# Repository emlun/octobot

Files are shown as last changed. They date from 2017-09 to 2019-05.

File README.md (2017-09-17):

octobot
=======

This is a hobby project of building an ALU, CPU, computer, or whatever it ends
up as before I tire of it, from basic components. Think of it as a learning and
art project more than anything practically useful.

Inspirations include:

- [That ALU built in minecraft][minecraft]
- [Boldport Club][boldport-club] for sending me beautiful, fun, whimsical and/or
  useful kits to assemble; and for its community of other tinkerers showing off
  their projects
- [Crash Course Computer Science][cccs] for making me think "that should be fun,
  how hard could it be?"
- The [MOnSter 6502][monster] and [Megaprocessor][megaprocessor]

Special thanks also to the [Boldport Club][boldport-club] community for
providing newbie help as I try to figure these things out!

[cccs]: https://www.youtube.com/watch?v=1I5ZMmrOfnA&list=PL8dPuuaLjXtNlUrzyH5r6jN9ulIgZBpdo&index=6
[minecraft]: https://www.youtube.com/watch?v=LGkkyKZVzug
[boldport-club]: http://www.boldport.club/
[monster]: http://monster6502.com/
[megaprocessor]: https://www.youtube.com/watch?v=z71h9XZbAWY

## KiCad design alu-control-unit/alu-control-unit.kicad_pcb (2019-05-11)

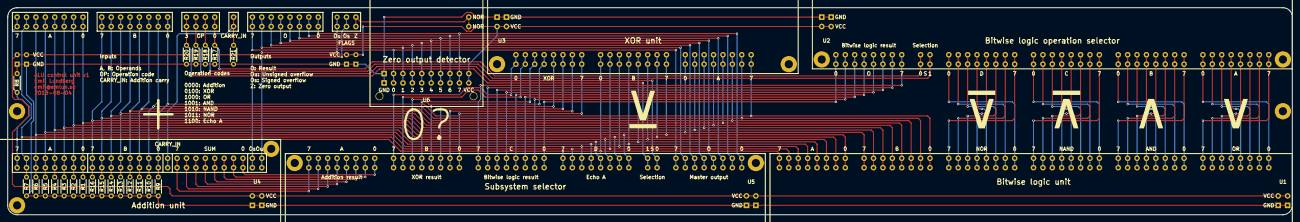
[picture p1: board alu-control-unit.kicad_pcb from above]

Board: 2 copper layers, 346.7 x 55.9 mm, 35 parts (0 on the bottom side), 90 nets.

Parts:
J1, J2, J5: Conn_01x08; J8x2-double_8_bit_bus_connector_1_indexed
J3: Conn_01x04; J4x2-double_4_bit_bus
J4: Conn_01x01; J1x2-double_1_bit_bus
J6: Conn_01x03; J3x2-double_3_bit_bus
J7, J7#2: PWR-2_pole_power_connector; PWR-double_2_pole_power_connector
R1, R2, R3, R4, R5, R6, R7, R8, R9, R10, R11, R12, R13, R14, R15, R16, R17, R18, R19, R20, R21: R; R_Axial_DIN0204_L3.6mm_D1.6mm_P5.08mm_Horizontal
U1: 8-bit-bitwise-logic
U2, U5: 4-way-8-bit-bus-selector
U3: 8_bit_xor; 8-bit-xor
U4: 8_bit_adder; 8-bit-adder
U6: 8-input-NOR; 8-input-nor

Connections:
/a0: J1.8, R1.2, U1.8, U3.9, U4.8, U5.32
/a1: J1.7, R2.2, U1.7, U3.10, U4.7, U5.31
/a2: J1.6, R3.2, U1.6, U3.11, U4.6, U5.30
/a3: J1.5, R4.2, U1.5, U3.12, U4.5, U5.29
/a4: J1.4, R5.2, U1.4, U3.13, U4.4, U5.28
/a5: J1.3, R6.2, U1.3, U3.14, U4.3, U5.27
/a6: J1.2, R7.2, U1.2, U3.15, U4.2, U5.26
/a7: J1.1, R8.2, U1.1, U3.16, U4.1, U5.25
/and0: U1.40, U2.16
/and1: U1.39, U2.15
/and2: U1.38, U2.14
/and3: U1.37, U2.13
/and4: U1.36, U2.12
/and5: U1.35, U2.11
/and6: U1.34, U2.10
/and7: U1.33, U2.9
/b0: J2.8, R9.2, U1.16, U3.1, U4.16
/b1: J2.7, R10.2, U1.15, U3.2, U4.15
/b2: J2.6, R11.2, U1.14, U3.3, U4.14
/b3: J2.5, R12.2, U1.13, U3.4, U4.13
/b4: J2.4, R13.2, U1.12, U3.5, U4.12
/b5: J2.3, R14.2, U1.11, U3.6, U4.11
/b6: J2.2, R15.2, U1.10, U3.7, U4.10
/b7: J2.1, R16.2, U1.9, U3.8, U4.9
/carry_in: J4.1, R21.2, U4.17
/ins0: J3.4, R17.2, U2.34
/ins1: J3.3, R18.2, U2.33
/ins2: J3.2, R19.2, U5.34
/ins3: J3.1, R20.2, U5.33
/logic_out0: U2.42, U5.24
/logic_out1: U2.41, U5.23
/logic_out2: U2.40, U5.22
/logic_out3: U2.39, U5.21
/logic_out4: U2.38, U5.20
/logic_out5: U2.37, U5.19
/logic_out6: U2.36, U5.18
/logic_out7: U2.35, U5.17
/nand0: U1.32, U2.24
/nand1: U1.31, U2.23
/nand2: U1.30, U2.22
/nand3: U1.29, U2.21
/nand4: U1.28, U2.20
/nand5: U1.27, U2.19
/nand6: U1.26, U2.18
/nand7: U1.25, U2.17
/nor0: U1.24, U2.32
/nor1: U1.23, U2.31
/nor2: U1.22, U2.30
/nor3: U1.21, U2.29
/nor4: U1.20, U2.28
/nor5: U1.19, U2.27
/nor6: U1.18, U2.26
/nor7: U1.17, U2.25
/ofl_sgn: J6.2, U4.26
/ofl_uns: J6.1, U4.27
/or0: U1.48, U2.8
/or1: U1.47, U2.7
/or2: U1.46, U2.6
/or3: U1.45, U2.5
/or4: U1.44, U2.4
/or5: U1.43, U2.3
/or6: U1.42, U2.2
/or7: U1.41, U2.1
/out0: J5.8, U5.42, U6.1
/out1: J5.7, U5.41, U6.2
/out2: J5.6, U5.40, U6.3
/out3: J5.5, U5.39, U6.4
/out4: J5.4, U5.38, U6.5
/out5: J5.3, U5.37, U6.6
/out6: J5.2, U5.36, U6.7
/out7: J5.1, U5.35, U6.8
/out_zero: J6.3, U6.9
/sum0: U4.25, U5.8
/sum1: U4.24, U5.7
/sum2: U4.23, U5.6
/sum3: U4.22, U5.5
/sum4: U4.21, U5.4
/sum5: U4.20, U5.3
/sum6: U4.19, U5.2
/sum7: U4.18, U5.1
/xor0: U3.17, U5.16
/xor1: U3.18, U5.15
/xor2: U3.19, U5.14
/xor3: U3.20, U5.13
/xor4: U3.21, U5.12
/xor5: U3.22, U5.11
/xor6: U3.23, U5.10
/xor7: U3.24, U5.9
GND: J7.1, J7#2.1, R1.1, R2.1, R3.1, R4.1, R5.1, R6.1, R7.1, R8.1, R9.1, R10.1, R11.1, R12.1, R13.1, R14.1, R15.1, R16.1, R17.1, R18.1, R19.1, R20.1, R21.1, U1.50, U2.44, U3.26, U4.29, U5.44, U6.11
VCC: J7.2, J7#2.2, U1.49, U2.43, U3.25, U4.28, U5.43, U6.10

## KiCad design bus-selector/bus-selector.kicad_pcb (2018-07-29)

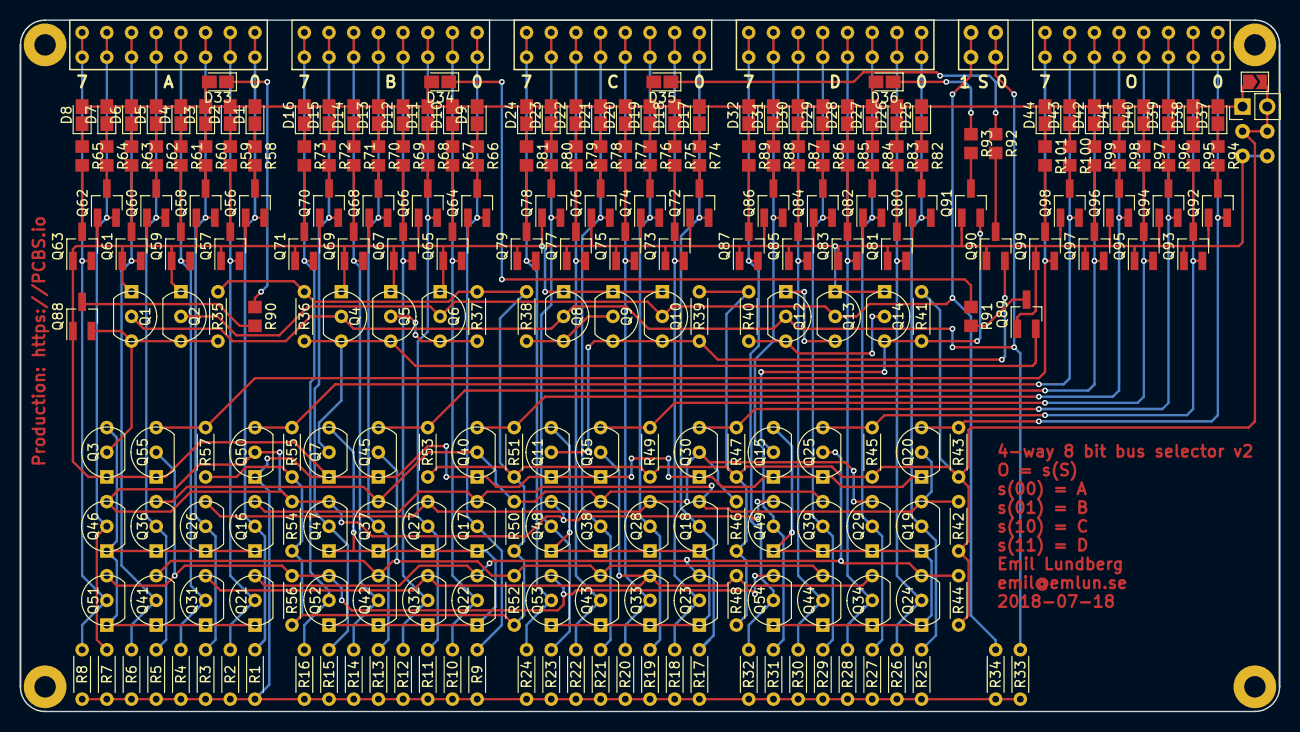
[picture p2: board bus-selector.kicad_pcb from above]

Board: 2 copper layers, 129.5 x 71.1 mm, 253 parts (0 on the bottom side), 153 nets.

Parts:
D1, D2, D3, D4, D5, D6, D7, D8, D9, D10, D11, D12, D13, D14, D15, D16, D17, D18, D19, D20, D21, D22, D23, D24, D25, D26, D27, D28, D29, D30, D31, D32, D33, D34, D35, D36, D37, D38, D39, D40, D41, D42, D43, D44: LED; LED_0805_2012Metric_Castellated
J1, J2, J3, J4, J6: Conn_01x08; J8x2-double_8_bit_bus_connector_1_indexed
J5: Conn_01x02; J2x2-double_2_bit_bus
J7: PWR-2_pole_power_connector; J2x2-double_2_pole_connector
JP1: Jumper_2_Open; PinHeader_1x02_P2.54mm_Vertical
JP2: SolderJumper_2_Open; SolderJumper-2_P1.3mm_Open_TrianglePad1.0x1.5mm
Q1, Q2, Q3, Q4, Q5, Q6, Q7, Q8, Q9, Q10, Q11, Q12, Q13, Q14, Q15, Q16, Q17, Q18, Q19, Q20, Q21, Q22, Q23, Q24, Q25, Q26, Q27, Q28, Q29, Q30, Q31, Q32, Q33, Q34, Q35, Q36, Q37, Q38, Q39, Q40, Q41, Q42, Q43, Q44, Q45, Q46, Q47, Q48, Q49, Q50, Q51, Q52, Q53, Q54, Q55: 2N7000; TO-92_Molded_Wide_Inline
Q56, Q57, Q58, Q59, Q60, Q61, Q62, Q63, Q64, Q65, Q66, Q67, Q68, Q69, Q70, Q71, Q72, Q73, Q74, Q75, Q76, Q77, Q78, Q79, Q80, Q81, Q82, Q83, Q84, Q85, Q86, Q87, Q88, Q89, Q90, Q91, Q92, Q93, Q94, Q95, Q96, Q97, Q98, Q99: 2N7000; SOT-23_Handsoldering
R1, R2, R3, R4, R5, R6, R7, R8, R9, R10, R11, R12, R13, R14, R15, R16, R17, R18, R19, R20, R21, R22, R23, R24, R25, R26, R27, R28, R29, R30, R31, R32, R33, R34, R35, R36, R37, R38, R39, R40, R41, R42, R43, R44, R45, R46, R47, R48, R49, R50, R51, R52, R53, R54, R55, R56, R57: R; R_Axial_DIN0204_L3.6mm_D1.6mm_P5.08mm_Horizontal
R58, R59, R60, R61, R62, R63, R64, R65, R66, R67, R68, R69, R70, R71, R72, R73, R74, R75, R76, R77, R78, R79, R80, R81, R82, R83, R84, R85, R86, R87, R88, R89, R90, R91, R92, R93, R94, R95, R96, R97, R98, R99, R100, R101: R; R_0805_2012Metric_Pad1.29x1.40mm_HandSolder

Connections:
/LED_PWR: D1.2, D2.2, D3.2, D4.2, D5.2, D6.2, D7.2, D8.2, D9.2, D10.2, D11.2, D12.2, D13.2, D14.2, D15.2, D16.2, D17.2, D18.2, D19.2, D20.2, D21.2, D22.2, D23.2, D24.2, D25.2, D26.2, D27.2, D28.2, D29.2, D30.2, D31.2, D32.2, D33.2, D34.2, D35.2, D36.2, D37.2, D38.2, D39.2, D40.2, D41.2, D42.2, D43.2, D44.2, JP1.1, JP2.1
/a0: J1.1, Q16.2, Q56.2, R1.1
/a1: J1.2, Q21.2, Q57.2, R2.1
/a2: J1.3, Q26.2, Q58.2, R3.1
/a3: J1.4, Q31.2, Q59.2, R4.1
/a4: J1.5, Q36.2, Q60.2, R5.1
/a5: J1.6, Q41.2, Q61.2, R6.1
/a6: J1.7, Q46.2, Q62.2, R7.1
/a7: J1.8, Q51.2, Q63.2, R8.1
/b0: J2.1, Q17.2, Q64.2, R9.1
/b1: J2.2, Q22.2, Q65.2, R10.1
/b2: J2.3, Q27.2, Q66.2, R11.1
/b3: J2.4, Q32.2, Q67.2, R12.1
/b4: J2.5, Q37.2, Q68.2, R13.1
/b5: J2.6, Q42.2, Q69.2, R14.1
/b6: J2.7, Q47.2, Q70.2, R15.1
/b7: J2.8, Q52.2, Q71.2, R16.1
/c0: J3.1, Q18.2, Q72.2, R17.1
/c1: J3.2, Q23.2, Q73.2, R18.1
/c2: J3.3, Q28.2, Q74.2, R19.1
/c3: J3.4, Q33.2, Q75.2, R20.1
/c4: J3.5, Q38.2, Q76.2, R21.1
/c5: J3.6, Q43.2, Q77.2, R22.1
/c6: J3.7, Q48.2, Q78.2, R23.1
/c7: J3.8, Q53.2, Q79.2, R24.1
/d0: J4.1, Q19.2, Q80.2, R25.1
/d1: J4.2, Q24.2, Q81.2, R26.1
/d2: J4.3, Q29.2, Q82.2, R27.1
/d3: J4.4, Q34.2, Q83.2, R28.1
/d4: J4.5, Q39.2, Q84.2, R29.1
/d5: J4.6, Q44.2, Q85.2, R30.1
/d6: J4.7, Q49.2, Q86.2, R31.1
/d7: J4.8, Q54.2, Q87.2, R32.1
/o0: J6.1, Q20.3, Q92.2, R43.2
/o1: J6.2, Q25.3, Q93.2, R45.2
/o2: J6.3, Q30.3, Q94.2, R47.2
/o3: J6.4, Q35.3, Q95.2, R49.2
/o4: J6.5, Q40.3, Q96.2, R51.2
/o5: J6.6, Q45.3, Q97.2, R53.2
/o6: J6.7, Q50.3, Q98.2, R55.2
/o7: J6.8, Q55.3, Q99.2, R57.2
/s0: J5.1, Q1.2, Q4.2, Q8.2, Q12.2, R33.1
/s1: J5.2, Q2.2, Q6.2, Q10.2, Q13.2, R34.1
/sa: Q1.3, Q2.3, Q3.2, Q88.2, R35.2
/sa_and: Q3.3, Q16.1, Q21.1, Q26.1, Q31.1, Q36.1, Q41.1, Q46.1, Q51.1
/sb: Q4.3, Q5.3, Q7.2, Q89.2, R36.2
/sb_and: Q7.3, Q17.1, Q22.1, Q27.1, Q32.1, Q37.1, Q42.1, Q47.1, Q52.1
/sc: Q9.3, Q10.3, Q11.2, Q90.2, R39.2
/sc_and: Q11.3, Q18.1, Q23.1, Q28.1, Q33.1, Q38.1, Q43.1, Q48.1, Q53.1
/sd: Q14.3, Q15.2, Q91.2, R41.2
/sd_and: Q15.3, Q19.1, Q24.1, Q29.1, Q34.1, Q39.1, Q44.1, Q49.1, Q54.1
GND: J7.1, Q1.1, Q2.1, Q3.1, Q4.1, Q5.1, Q6.1, Q7.1, Q8.1, Q9.1, Q10.1, Q11.1, Q13.1, Q14.1, Q15.1, Q20.1, Q25.1, Q30.1, Q35.1, Q40.1, Q45.1, Q50.1, Q55.1, Q56.1, Q57.1, Q58.1, Q59.1, Q60.1, Q61.1, Q62.1, Q63.1, Q64.1, Q65.1, Q66.1, Q67.1, Q68.1, Q69.1, Q70.1, Q71.1, Q72.1, Q73.1, Q74.1, Q75.1, Q76.1, Q77.1, Q78.1, Q79.1, Q80.1, Q81.1, Q82.1, Q83.1, Q84.1, Q85.1, Q86.1, Q87.1, Q88.1, Q89.1, Q90.1, Q91.1, Q92.1, Q93.1, Q94.1, Q95.1, Q96.1, Q97.1, Q98.1, Q99.1, R1.2, R2.2, R3.2, R4.2, R5.2, R6.2, R7.2, R8.2, R9.2, R10.2, R11.2, R12.2, R13.2, R14.2, R15.2, R16.2, R17.2, R18.2, R19.2, R20.2, R21.2, R22.2, R23.2, R24.2, R25.2, R26.2, R27.2, R28.2, R29.2, R30.2, R31.2, R32.2, R33.2, R34.2
unnamed: D1.1, R58.1
unnamed: D2.1, R59.1
unnamed: D3.1, R60.1
unnamed: D4.1, R61.1
unnamed: D5.1, R62.1
unnamed: D6.1, R63.1
unnamed: D7.1, R64.1
unnamed: D8.1, R65.1
unnamed: D9.1, R66.1
unnamed: D10.1, R67.1
unnamed: D11.1, R68.1
unnamed: D12.1, R69.1
unnamed: D13.1, R70.1
unnamed: D14.1, R71.1
unnamed: D15.1, R72.1
unnamed: D16.1, R73.1
unnamed: D17.1, R74.1
unnamed: D18.1, R75.1
unnamed: D19.1, R76.1
unnamed: D20.1, R77.1
unnamed: D21.1, R78.1
unnamed: D22.1, R79.1
unnamed: D23.1, R80.1
unnamed: D24.1, R81.1
unnamed: D25.1, R82.1
unnamed: D26.1, R83.1
unnamed: D27.1, R84.1
unnamed: D28.1, R85.1
unnamed: D29.1, R86.1
unnamed: D30.1, R87.1
unnamed: D31.1, R88.1
unnamed: D32.1, R89.1
unnamed: D33.1, R90.1
unnamed: D34.1, R91.1
unnamed: D35.1, R92.1
unnamed: D36.1, R93.1
unnamed: D37.1, R94.1
unnamed: D38.1, R95.1
unnamed: D39.1, R96.1
unnamed: D40.1, R97.1
unnamed: D41.1, R98.1
unnamed: D42.1, R99.1
unnamed: D43.1, R100.1
unnamed: D44.1, R101.1
unnamed: Q5.2, Q6.3, R37.2
unnamed: Q8.3, Q9.2, R38.2
unnamed: Q12.1, Q13.3
unnamed: Q12.3, Q14.2, R40.2
unnamed: Q16.3, Q17.3, Q18.3, Q19.3, Q20.2, R42.2
unnamed: Q21.3, Q22.3, Q23.3, Q24.3, Q25.2, R44.2
unnamed: Q26.3, Q27.3, Q28.3, Q29.3, Q30.2, R46.2
unnamed: Q31.3, Q32.3, Q33.3, Q34.3, Q35.2, R48.2
unnamed: Q36.3, Q37.3, Q38.3, Q39.3, Q40.2, R50.2
unnamed: Q41.3, Q42.3, Q43.3, Q44.3, Q45.2, R52.2
unnamed: Q46.3, Q47.3, Q48.3, Q49.3, Q50.2, R54.2
unnamed: Q51.3, Q52.3, Q53.3, Q54.3, Q55.2, R56.2
unnamed: Q56.3, R58.2
unnamed: Q57.3, R59.2
unnamed: Q58.3, R60.2
unnamed: Q59.3, R61.2
unnamed: Q60.3, R62.2
unnamed: Q61.3, R63.2
unnamed: Q62.3, R64.2
unnamed: Q63.3, R65.2
unnamed: Q64.3, R66.2
unnamed: Q65.3, R67.2
unnamed: Q66.3, R68.2
unnamed: Q67.3, R69.2
unnamed: Q68.3, R70.2
unnamed: Q69.3, R71.2
unnamed: Q70.3, R72.2
unnamed: Q71.3, R73.2
unnamed: Q72.3, R74.2
unnamed: Q73.3, R75.2
unnamed: Q74.3, R76.2
unnamed: Q75.3, R77.2
unnamed: Q76.3, R78.2
unnamed: Q77.3, R79.2
unnamed: Q78.3, R80.2
unnamed: Q79.3, R81.2
unnamed: Q80.3, R82.2
unnamed: Q81.3, R83.2
unnamed: Q82.3, R84.2
unnamed: Q83.3, R85.2
unnamed: Q84.3, R86.2
unnamed: Q85.3, R87.2
unnamed: Q86.3, R88.2
unnamed: Q87.3, R89.2
unnamed: Q88.3, R90.2
unnamed: Q89.3, R91.2
unnamed: Q90.3, R92.2
unnamed: Q91.3, R93.2
unnamed: Q92.3, R94.2
unnamed: Q93.3, R95.2
unnamed: Q94.3, R96.2
unnamed: Q95.3, R97.2
unnamed: Q96.3, R98.2
unnamed: Q97.3, R99.2
unnamed: Q98.3, R100.2
unnamed: Q99.3, R101.2
VCC: J7.2, JP1.2, JP2.2, R35.1, R36.1, R37.1, R38.1, R39.1, R40.1, R41.1, R42.1, R43.1, R44.1, R45.1, R46.1, R47.1, R48.1, R49.1, R50.1, R51.1, R52.1, R53.1, R54.1, R55.1, R56.1, R57.1

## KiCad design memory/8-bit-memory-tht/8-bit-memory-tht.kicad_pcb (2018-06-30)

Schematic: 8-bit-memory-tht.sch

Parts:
D1, D2, D3, D4, D5, D6, D7, D8, D9, D10, D11, D12, D13, D14, D15, D16, D17: LED; LED_0805_2012Metric_Pad1.12x1.40mm_HandSolder
J1: J1-1_bit_bus; J1x2-double_1_bit_bus
J2, J3: J8-8_bit_bus_connector; J8x2-double_8_bit_bus_connector
J4: PWR-2_pole_power_connector; J2x2-double_2_pole_connector
JP1: Jumper_2_Open; PinHeader_1x02_P2.54mm_Vertical
JP2: SolderJumper_2_Bridged; SolderJumper-2_P1.3mm_Open_TrianglePad1.0x1.5mm
Q1, Q2, Q3, Q4, Q5, Q6, Q7, Q8, Q9, Q10, Q11, Q12, Q13, Q14, Q15, Q16, Q17, Q18, Q19, Q20, Q21, Q22, Q23, Q24, Q25, Q26, Q27, Q28, Q29, Q30, Q31, Q32, Q33, Q34, Q35, Q36, Q37, Q38, Q39, Q40, Q41, Q42, Q43, Q44, Q45, Q46, Q47, Q48, Q49, Q50, Q51, Q52, Q53, Q54, Q55, Q56, Q57, Q58, Q59, Q60, Q61, Q62, Q63, Q64, Q65, Q66, Q67, Q68, Q69, Q70, Q71, Q72, Q73, Q74, Q75, Q76, Q77, Q78, Q79, Q80, Q81, Q82, Q83, Q84, Q85, Q86, Q87, Q88, Q89: 2N7000; TO-92_Molded_Wide_Inline
Q90, Q91, Q92, Q93, Q94, Q95, Q96, Q97, Q98, Q99, Q100, Q101, Q102, Q103, Q104, Q105, Q106: 2N7000; SOT-23_Handsoldering
R1, R2, R3, R4, R5, R6, R7, R8, R9, R10, R11, R12, R13, R14, R15, R16, R17, R18, R19, R20, R21, R22, R23, R24, R25, R26, R27, R28, R29, R30, R31, R32, R33, R34, R35, R36, R37, R38, R39, R40, R41, R42, R43, R44, R45, R46, R47, R48, R49, R50, R51, R52, R53, R54, R55, R56, R57, R58, R59, R60, R61, R62, R63, R64, R65: R; R_Axial_DIN0204_L3.6mm_D1.6mm_P5.08mm_Horizontal
R66, R67, R68, R69, R70, R71, R72, R73, R74, R75, R76, R77, R78, R79, R80, R81, R82: R; R_0603_1608Metric_Pad0.99x1.00mm_HandSolder

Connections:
/FB0: Q5.2, Q8.3, Q9.3, Q10.2, R6.2
/FB1: Q16.2, Q19.3, Q20.3, Q21.2, R14.2
/FB2: Q27.2, Q30.3, Q31.3, Q32.2, R22.2
/FB3: Q38.2, Q41.3, Q42.3, Q43.2, R30.2
/FB4: Q49.2, Q52.3, Q53.3, Q54.2, R38.2
/FB5: Q60.2, Q63.3, Q64.3, Q65.2, R46.2
/FB6: Q71.2, Q74.3, Q75.3, Q76.2, R54.2
/FB7: Q82.2, Q85.3, Q86.3, Q87.2, R62.2
/I0: J2.0, Q1.2, Q6.2, Q91.2, R1.2
/I1: J2.1, Q12.2, Q17.2, Q92.2, R9.2
/I2: J2.2, Q23.2, Q28.2, Q93.2, R17.2
/I3: J2.3, Q34.2, Q39.2, Q94.2, R25.2
/I4: J2.4, Q45.2, Q50.2, Q95.2, R33.2
/I5: J2.5, Q56.2, Q61.2, Q96.2, R41.2
/I6: J2.6, Q67.2, Q72.2, Q97.2, R49.2
/I7: J2.7, Q78.2, Q83.2, Q98.2, R57.2
/O0: J3.0, Q11.3, Q99.2, R8.2
/O1: J3.1, Q22.3, Q100.2, R16.2
/O2: J3.2, Q33.3, Q101.2, R24.2
/O3: J3.3, Q44.3, Q102.2, R32.2
/O4: J3.4, Q55.3, Q103.2, R40.2
/O5: J3.5, Q66.3, Q104.2, R48.2
/O6: J3.6, Q77.3, Q105.2, R56.2
/O7: J3.7, Q88.3, Q106.2, R64.2
/W: J1.1, Q89.2, Q90.2
/notW: Q3.2, Q7.2, Q14.2, Q18.2, Q25.2, Q29.2, Q36.2, Q40.2, Q47.2, Q51.2, Q58.2, Q62.2, Q69.2, Q73.2, Q80.2, Q84.2, Q89.3, R65.2
GND: J4.1 (GND), Q1.1, Q2.1, Q3.1, Q4.1, Q5.1, Q6.1, Q7.1, Q8.1, Q9.1, Q10.1, Q11.1, Q12.1, Q13.1, Q14.1, Q15.1, Q16.1, Q17.1, Q18.1, Q19.1, Q20.1, Q21.1, Q22.1, Q23.1, Q24.1, Q25.1, Q26.1, Q27.1, Q28.1, Q29.1, Q30.1, Q31.1, Q32.1, Q33.1, Q34.1, Q35.1, Q36.1, Q37.1, Q38.1, Q39.1, Q40.1, Q41.1, Q42.1, Q43.1, Q44.1, Q45.1, Q46.1, Q47.1, Q48.1, Q49.1, Q50.1, Q51.1, Q52.1, Q53.1, Q54.1, Q55.1, Q56.1, Q57.1, Q58.1, Q59.1, Q60.1, Q61.1, Q62.1, Q63.1, Q64.1, Q65.1, Q66.1, Q67.1, Q68.1, Q69.1, Q70.1, Q71.1, Q72.1, Q73.1, Q74.1, Q75.1, Q76.1, Q77.1, Q78.1, Q79.1, Q80.1, Q81.1, Q82.1, Q83.1, Q84.1, Q85.1, Q86.1, Q87.1, Q88.1, Q89.1, Q90.1, Q91.1, Q92.1, Q93.1, Q94.1, Q95.1, Q96.1, Q97.1, Q98.1, Q99.1, Q100.1, Q101.1, Q102.1, Q103.1, Q104.1, Q105.1, Q106.1, R1.1, R9.1, R17.1, R25.1, R33.1, R41.1, R49.1, R57.1
unnamed: D1.1, R66.2
unnamed: D1.2, D2.2, D3.2, D4.2, D5.2, D6.2, D7.2, D8.2, D9.2, D10.2, D11.2, D12.2, D13.2, D14.2, D15.2, D16.2, D17.2, JP1.2, JP2.2
unnamed: D2.1, R67.2
unnamed: D3.1, R68.2
unnamed: D4.1, R69.2
unnamed: D5.1, R70.2
unnamed: D6.1, R71.2
unnamed: D7.1, R72.2
unnamed: D8.1, R73.2
unnamed: D9.1, R74.2
unnamed: D10.1, R75.2
unnamed: D11.1, R76.2
unnamed: D12.1, R77.2
unnamed: D13.1, R78.2
unnamed: D14.1, R79.2
unnamed: D15.1, R80.2
unnamed: D16.1, R81.2
unnamed: D17.1, R82.2
unnamed: Q1.3, Q2.2, R2.2
unnamed: Q2.3, Q3.3, Q4.2, R3.2
unnamed: Q4.3, Q5.3, Q9.2, R4.2
unnamed: Q6.3, Q7.3, Q8.2, R5.2
unnamed: Q10.3, Q11.2, R7.2
unnamed: Q12.3, Q13.2, R10.2
unnamed: Q13.3, Q14.3, Q15.2, R11.2
unnamed: Q15.3, Q16.3, Q20.2, R12.2
unnamed: Q17.3, Q18.3, Q19.2, R13.2
unnamed: Q21.3, Q22.2, R15.2
unnamed: Q23.3, Q24.2, R18.2
unnamed: Q24.3, Q25.3, Q26.2, R19.2
unnamed: Q26.3, Q27.3, Q31.2, R20.2
unnamed: Q28.3, Q29.3, Q30.2, R21.2
unnamed: Q32.3, Q33.2, R23.2
unnamed: Q34.3, Q35.2, R26.2
unnamed: Q35.3, Q36.3, Q37.2, R27.2
unnamed: Q37.3, Q38.3, Q42.2, R28.2
unnamed: Q39.3, Q40.3, Q41.2, R29.2
unnamed: Q43.3, Q44.2, R31.2
unnamed: Q45.3, Q46.2, R34.2
unnamed: Q46.3, Q47.3, Q48.2, R35.2
unnamed: Q48.3, Q49.3, Q53.2, R36.2
unnamed: Q50.3, Q51.3, Q52.2, R37.2
unnamed: Q54.3, Q55.2, R39.2
unnamed: Q56.3, Q57.2, R42.2
unnamed: Q57.3, Q58.3, Q59.2, R43.2
unnamed: Q59.3, Q60.3, Q64.2, R44.2
unnamed: Q61.3, Q62.3, Q63.2, R45.2
unnamed: Q65.3, Q66.2, R47.2
unnamed: Q67.3, Q68.2, R50.2
unnamed: Q68.3, Q69.3, Q70.2, R51.2
unnamed: Q70.3, Q71.3, Q75.2, R52.2
unnamed: Q72.3, Q73.3, Q74.2, R53.2
unnamed: Q76.3, Q77.2, R55.2
unnamed: Q78.3, Q79.2, R58.2
unnamed: Q79.3, Q80.3, Q81.2, R59.2
unnamed: Q81.3, Q82.3, Q86.2, R60.2
unnamed: Q83.3, Q84.3, Q85.2, R61.2
unnamed: Q87.3, Q88.2, R63.2
unnamed: Q90.3, R82.1
unnamed: Q91.3, R66.1
unnamed: Q92.3, R67.1
unnamed: Q93.3, R68.1
unnamed: Q94.3, R69.1
unnamed: Q95.3, R70.1
unnamed: Q96.3, R71.1
unnamed: Q97.3, R72.1
unnamed: Q98.3, R73.1
unnamed: Q99.3, R74.1
unnamed: Q100.3, R75.1
unnamed: Q101.3, R76.1
unnamed: Q102.3, R77.1
unnamed: Q103.3, R78.1
unnamed: Q104.3, R79.1
unnamed: Q105.3, R80.1
unnamed: Q106.3, R81.1
VCC: J4.2 (VCC), JP1.1, JP2.1, R2.1, R3.1, R4.1, R5.1, R6.1, R7.1, R8.1, R10.1, R11.1, R12.1, R13.1, R14.1, R15.1, R16.1, R18.1, R19.1, R20.1, R21.1, R22.1, R23.1, R24.1, R26.1, R27.1, R28.1, R29.1, R30.1, R31.1, R32.1, R34.1, R35.1, R36.1, R37.1, R38.1, R39.1, R40.1, R42.1, R43.1, R44.1, R45.1, R46.1, R47.1, R48.1, R50.1, R51.1, R52.1, R53.1, R54.1, R55.1, R56.1, R58.1, R59.1, R60.1, R61.1, R62.1, R63.1, R64.1, R65.1

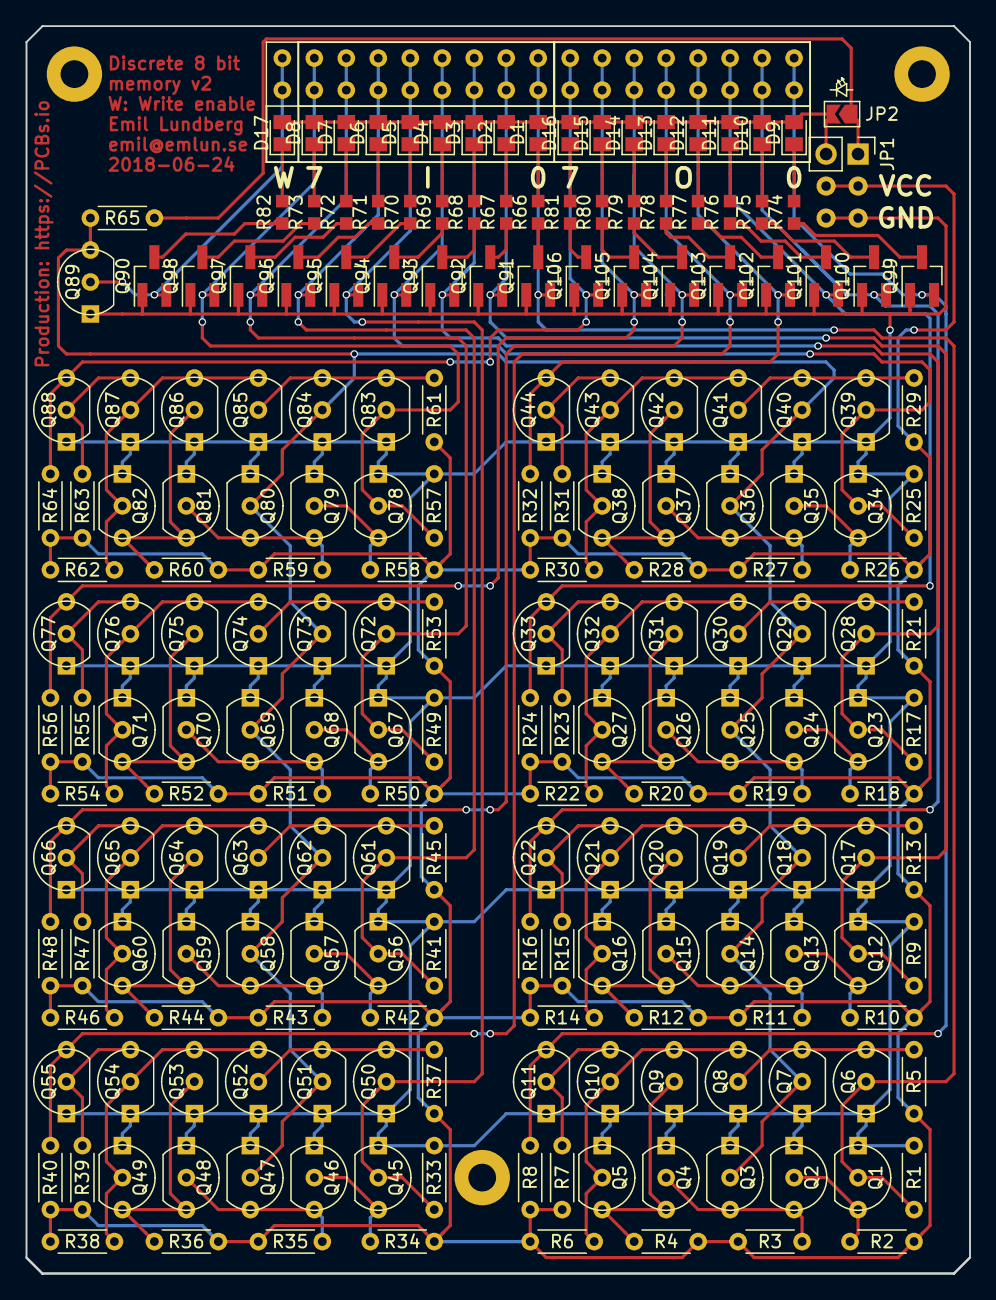
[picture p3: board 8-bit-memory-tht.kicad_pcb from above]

Board: 2 copper layers, 74.9 x 99.1 mm, 211 parts (0 on the bottom side), 103 nets.

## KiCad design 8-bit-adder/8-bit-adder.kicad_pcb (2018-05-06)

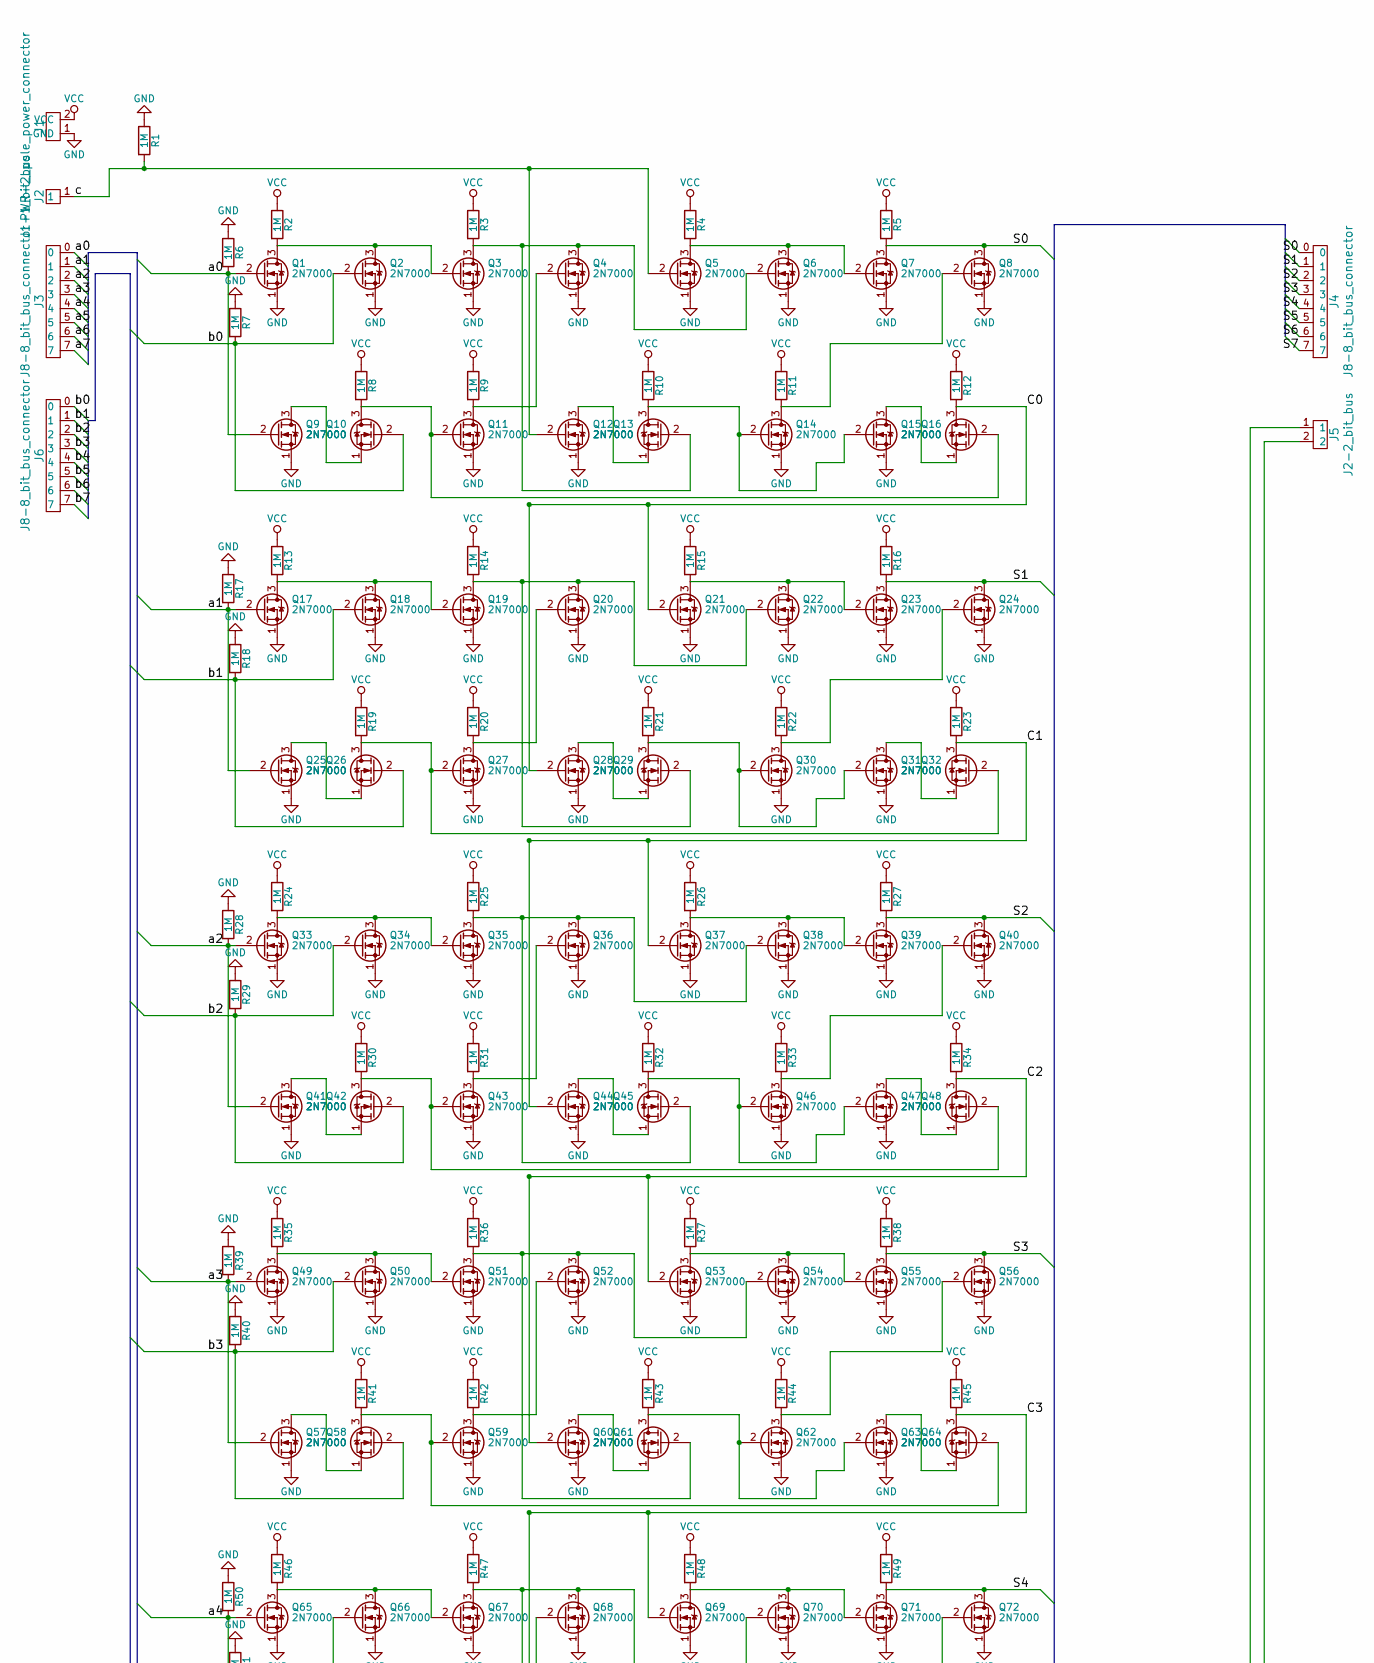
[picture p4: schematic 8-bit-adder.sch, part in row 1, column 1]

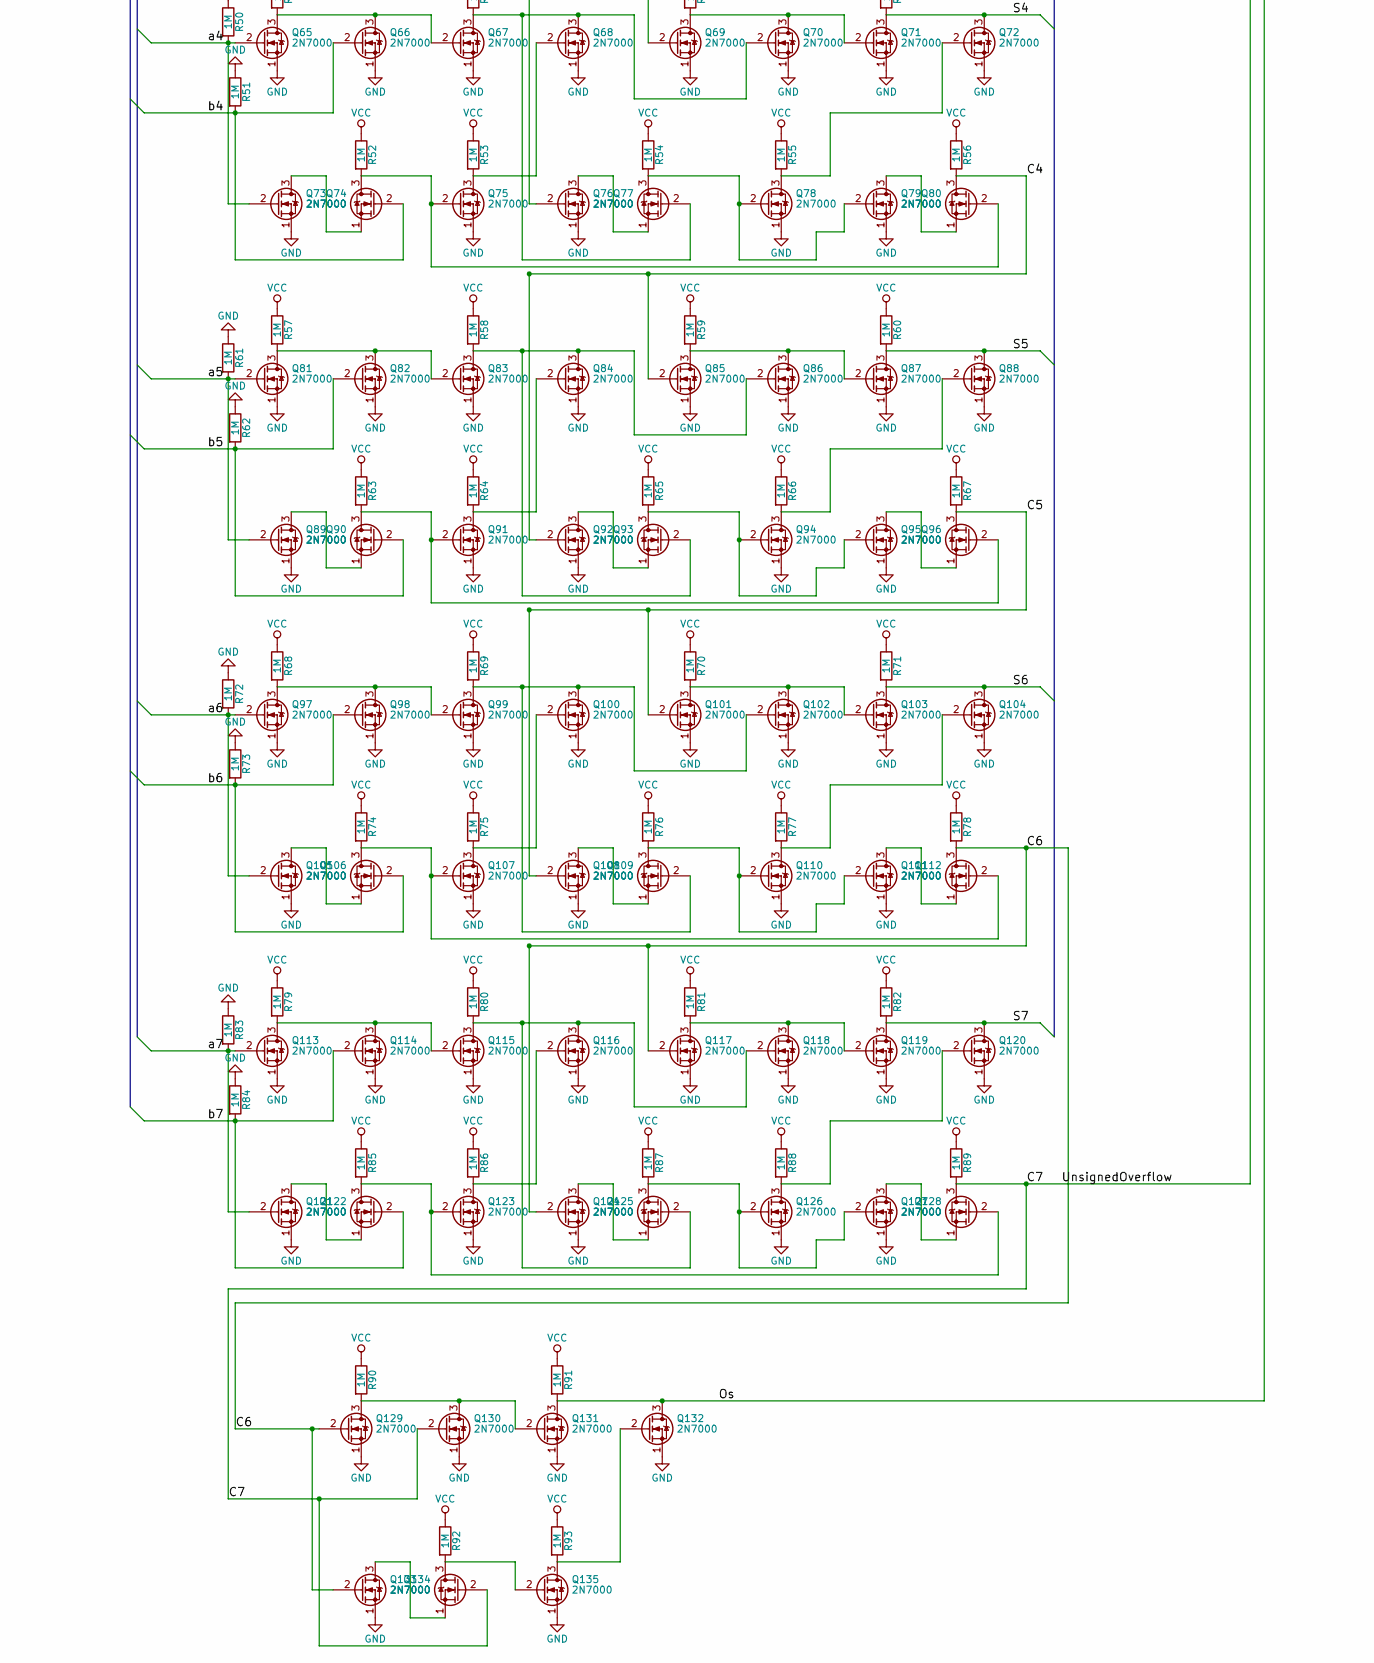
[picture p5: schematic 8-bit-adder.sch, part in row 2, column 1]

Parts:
J1: PWR-2_pole_power_connector; J2x2-double_2_pole_connector
J2: J1-1_bit_bus; J1x2-double_1_bit_bus
J3, J4, J6: J8-8_bit_bus_connector; J8x2-double_8_bit_bus_connector
J5: J2-2_bit_bus; J2x2-double_2_bit_bus
Q1, Q2, Q3, Q4, Q5, Q6, Q7, Q8, Q9, Q10, Q11, Q12, Q13, Q14, Q15, Q16, Q17, Q18, Q19, Q20, Q21, Q22, Q23, Q24, Q25, Q26, Q27, Q28, Q29, Q30, Q31, Q32, Q33, Q34, Q35, Q36, Q37, Q38, Q39, Q40, Q41, Q42, Q43, Q44, Q45, Q46, Q47, Q48, Q49, Q50, Q51, Q52, Q53, Q54, Q55, Q56, Q57, Q58, Q59, Q60, Q61, Q62, Q63, Q64, Q65, Q66, Q67, Q68, Q69, Q70, Q71, Q72, Q73, Q74, Q75, Q76, Q77, Q78, Q79, Q80, Q81, Q82, Q83, Q84, Q85, Q86, Q87, Q88, Q89, Q90, Q91, Q92, Q93, Q94, Q95, Q96, Q97, Q98, Q99, Q100, Q101, Q102, Q103, Q104, Q105, Q106, Q107, Q108, Q109, Q110, Q111, Q112, Q113, Q114, Q115, Q116, Q117, Q118, Q119, Q120, Q121, Q122, Q123, Q124, Q125, Q126, Q127, Q128, Q129, Q130, Q131, Q132, Q133, Q134, Q135: 2N7000; TO-92_Molded_Wide_Inline
R1, R2, R3, R4, R5, R6, R7, R8, R9, R10, R11, R12, R13, R14, R15, R16, R17, R18, R19, R20, R21, R22, R23, R24, R25, R26, R27, R28, R29, R30, R31, R32, R33, R34, R35, R36, R37, R38, R39, R40, R41, R42, R43, R44, R45, R46, R47, R48, R49, R50, R51, R52, R53, R54, R55, R56, R57, R58, R59, R60, R61, R62, R63, R64, R65, R66, R67, R68, R69, R70, R71, R72, R73, R74, R75, R76, R77, R78, R79, R80, R81, R82, R83, R84, R85, R86, R87, R88, R89, R90, R91, R92, R93: 1M; R_Axial_DIN0204_L3.6mm_D1.6mm_P5.08mm_Horizontal

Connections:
/C0: Q16.3 (D), Q21.2 (G), Q28.2 (G), R12.2
/C1: Q32.3 (D), Q37.2 (G), Q44.2 (G), R23.2
/C2: Q48.3 (D), Q53.2 (G), Q60.2 (G), R34.2
/C3: Q64.3 (D), Q69.2 (G), Q76.2 (G), R45.2
/C4: Q80.3 (D), Q85.2 (G), Q92.2 (G), R56.2
/C5: Q96.3 (D), Q101.2 (G), Q108.2 (G), R67.2
/C6: Q112.3 (D), Q117.2 (G), Q124.2 (G), Q129.2 (G), Q133.2 (G), R78.2
/C7: J5.1, Q128.3 (D), Q130.2 (G), Q134.2 (G), R89.2
/Os: J5.2, Q131.3 (D), Q132.3 (D), R91.2
/S0: J4.0, Q7.3 (D), Q8.3 (D), R5.2
/S1: J4.1, Q23.3 (D), Q24.3 (D), R16.2
/S2: J4.2, Q39.3 (D), Q40.3 (D), R27.2
/S3: J4.3, Q55.3 (D), Q56.3 (D), R38.2
/S4: J4.4, Q71.3 (D), Q72.3 (D), R49.2
/S5: J4.5, Q87.3 (D), Q88.3 (D), R60.2
/S6: J4.6, Q103.3 (D), Q104.3 (D), R71.2
/S7: J4.7, Q119.3 (D), Q120.3 (D), R82.2
/a0: J3.0, Q1.2 (G), Q9.2 (G), R6.2
/a1: J3.1, Q17.2 (G), Q25.2 (G), R17.2
/a2: J3.2, Q33.2 (G), Q41.2 (G), R28.2
/a3: J3.3, Q49.2 (G), Q57.2 (G), R39.2
/a4: J3.4, Q65.2 (G), Q73.2 (G), R50.2
/a5: J3.5, Q81.2 (G), Q89.2 (G), R61.2
/a6: J3.6, Q97.2 (G), Q105.2 (G), R72.2
/a7: J3.7, Q113.2 (G), Q121.2 (G), R83.2
/b0: J6.0, Q2.2 (G), Q10.2 (G), R7.2
/b1: J6.1, Q18.2 (G), Q26.2 (G), R18.2
/b2: J6.2, Q34.2 (G), Q42.2 (G), R29.2
/b3: J6.3, Q50.2 (G), Q58.2 (G), R40.2
/b4: J6.4, Q66.2 (G), Q74.2 (G), R51.2
/b5: J6.5, Q82.2 (G), Q90.2 (G), R62.2
/b6: J6.6, Q98.2 (G), Q106.2 (G), R73.2
/b7: J6.7, Q114.2 (G), Q122.2 (G), R84.2
/c: J2.1, Q5.2 (G), Q12.2 (G), R1.2
GND: J1.1 (GND), Q1.1 (S), Q2.1 (S), Q3.1 (S), Q4.1 (S), Q5.1 (S), Q6.1 (S), Q7.1 (S), Q8.1 (S), Q9.1 (S), Q11.1 (S), Q12.1 (S), Q14.1 (S), Q15.1 (S), Q17.1 (S), Q18.1 (S), Q19.1 (S), Q20.1 (S), Q21.1 (S), Q22.1 (S), Q23.1 (S), Q24.1 (S), Q25.1 (S), Q27.1 (S), Q28.1 (S), Q30.1 (S), Q31.1 (S), Q33.1 (S), Q34.1 (S), Q35.1 (S), Q36.1 (S), Q37.1 (S), Q38.1 (S), Q39.1 (S), Q40.1 (S), Q41.1 (S), Q43.1 (S), Q44.1 (S), Q46.1 (S), Q47.1 (S), Q49.1 (S), Q50.1 (S), Q51.1 (S), Q52.1 (S), Q53.1 (S), Q54.1 (S), Q55.1 (S), Q56.1 (S), Q57.1 (S), Q59.1 (S), Q60.1 (S), Q62.1 (S), Q63.1 (S), Q65.1 (S), Q66.1 (S), Q67.1 (S), Q68.1 (S), Q69.1 (S), Q70.1 (S), Q71.1 (S), Q72.1 (S), Q73.1 (S), Q75.1 (S), Q76.1 (S), Q78.1 (S), Q79.1 (S), Q81.1 (S), Q82.1 (S), Q83.1 (S), Q84.1 (S), Q85.1 (S), Q86.1 (S), Q87.1 (S), Q88.1 (S), Q89.1 (S), Q91.1 (S), Q92.1 (S), Q94.1 (S), Q95.1 (S), Q97.1 (S), Q98.1 (S), Q99.1 (S), Q100.1 (S), Q101.1 (S), Q102.1 (S), Q103.1 (S), Q104.1 (S), Q105.1 (S), Q107.1 (S), Q108.1 (S), Q110.1 (S), Q111.1 (S), Q113.1 (S), Q114.1 (S), Q115.1 (S), Q116.1 (S), Q117.1 (S), Q118.1 (S), Q119.1 (S), Q120.1 (S), Q121.1 (S), Q123.1 (S), Q124.1 (S), Q126.1 (S), Q127.1 (S), Q129.1 (S), Q130.1 (S), Q131.1 (S), Q132.1 (S), Q133.1 (S), Q135.1 (S), R1.1, R6.1, R7.1, R17.1, R18.1, R28.1, R29.1, R39.1, R40.1, R50.1, R51.1, R61.1, R62.1, R72.1, R73.1, R83.1, R84.1
unnamed: Q1.3 (D), Q2.3 (D), Q3.2 (G), R2.2
unnamed: Q5.3 (D), Q6.3 (D), Q7.2 (G), R4.2
unnamed: Q9.3 (D), Q10.1 (S)
unnamed: Q10.3 (D), Q11.2 (G), Q16.2 (G), R8.2
unnamed: Q4.2 (G), Q11.3 (D), R9.2
unnamed: Q12.3 (D), Q13.1 (S)
unnamed: Q3.3 (D), Q4.3 (D), Q6.2 (G), Q13.2 (G), R3.2
unnamed: Q13.3 (D), Q14.2 (G), Q15.2 (G), R10.2
unnamed: Q8.2 (G), Q14.3 (D), R11.2
unnamed: Q15.3 (D), Q16.1 (S)
unnamed: Q17.3 (D), Q18.3 (D), Q19.2 (G), R13.2
unnamed: Q19.3 (D), Q20.3 (D), Q22.2 (G), Q29.2 (G), R14.2
unnamed: Q20.2 (G), Q27.3 (D), R20.2
unnamed: Q21.3 (D), Q22.3 (D), Q23.2 (G), R15.2
unnamed: Q24.2 (G), Q30.3 (D), R22.2
unnamed: Q25.3 (D), Q26.1 (S)
unnamed: Q26.3 (D), Q27.2 (G), Q32.2 (G), R19.2
unnamed: Q28.3 (D), Q29.1 (S)
unnamed: Q29.3 (D), Q30.2 (G), Q31.2 (G), R21.2
unnamed: Q31.3 (D), Q32.1 (S)
unnamed: Q33.3 (D), Q34.3 (D), Q35.2 (G), R24.2
unnamed: Q35.3 (D), Q36.3 (D), Q38.2 (G), Q45.2 (G), R25.2
unnamed: Q36.2 (G), Q43.3 (D), R31.2
unnamed: Q37.3 (D), Q38.3 (D), Q39.2 (G), R26.2
unnamed: Q40.2 (G), Q46.3 (D), R33.2
unnamed: Q41.3 (D), Q42.1 (S)
unnamed: Q42.3 (D), Q43.2 (G), Q48.2 (G), R30.2
unnamed: Q44.3 (D), Q45.1 (S)
unnamed: Q45.3 (D), Q46.2 (G), Q47.2 (G), R32.2
unnamed: Q47.3 (D), Q48.1 (S)
unnamed: Q49.3 (D), Q50.3 (D), Q51.2 (G), R35.2
unnamed: Q51.3 (D), Q52.3 (D), Q54.2 (G), Q61.2 (G), R36.2
unnamed: Q52.2 (G), Q59.3 (D), R42.2
unnamed: Q53.3 (D), Q54.3 (D), Q55.2 (G), R37.2
unnamed: Q56.2 (G), Q62.3 (D), R44.2
unnamed: Q57.3 (D), Q58.1 (S)
unnamed: Q58.3 (D), Q59.2 (G), Q64.2 (G), R41.2
unnamed: Q60.3 (D), Q61.1 (S)
unnamed: Q61.3 (D), Q62.2 (G), Q63.2 (G), R43.2
unnamed: Q63.3 (D), Q64.1 (S)
unnamed: Q65.3 (D), Q66.3 (D), Q67.2 (G), R46.2
unnamed: Q67.3 (D), Q68.3 (D), Q70.2 (G), Q77.2 (G), R47.2
unnamed: Q68.2 (G), Q75.3 (D), R53.2
unnamed: Q69.3 (D), Q70.3 (D), Q71.2 (G), R48.2
unnamed: Q72.2 (G), Q78.3 (D), R55.2
unnamed: Q73.3 (D), Q74.1 (S)
unnamed: Q74.3 (D), Q75.2 (G), Q80.2 (G), R52.2
unnamed: Q76.3 (D), Q77.1 (S)
unnamed: Q77.3 (D), Q78.2 (G), Q79.2 (G), R54.2
unnamed: Q79.3 (D), Q80.1 (S)
unnamed: Q81.3 (D), Q82.3 (D), Q83.2 (G), R57.2
unnamed: Q83.3 (D), Q84.3 (D), Q86.2 (G), Q93.2 (G), R58.2
unnamed: Q84.2 (G), Q91.3 (D), R64.2
unnamed: Q85.3 (D), Q86.3 (D), Q87.2 (G), R59.2
unnamed: Q88.2 (G), Q94.3 (D), R66.2
unnamed: Q89.3 (D), Q90.1 (S)
unnamed: Q90.3 (D), Q91.2 (G), Q96.2 (G), R63.2
unnamed: Q92.3 (D), Q93.1 (S)
unnamed: Q93.3 (D), Q94.2 (G), Q95.2 (G), R65.2
unnamed: Q95.3 (D), Q96.1 (S)
unnamed: Q97.3 (D), Q98.3 (D), Q99.2 (G), R68.2
unnamed: Q100.2 (G), Q107.3 (D), R75.2
unnamed: Q99.3 (D), Q100.3 (D), Q102.2 (G), Q109.2 (G), R69.2
unnamed: Q101.3 (D), Q102.3 (D), Q103.2 (G), R70.2
unnamed: Q104.2 (G), Q110.3 (D), R77.2
unnamed: Q105.3 (D), Q106.1 (S)
unnamed: Q106.3 (D), Q107.2 (G), Q112.2 (G), R74.2
unnamed: Q108.3 (D), Q109.1 (S)
unnamed: Q109.3 (D), Q110.2 (G), Q111.2 (G), R76.2
unnamed: Q111.3 (D), Q112.1 (S)
unnamed: Q113.3 (D), Q114.3 (D), Q115.2 (G), R79.2
unnamed: Q115.3 (D), Q116.3 (D), Q118.2 (G), Q125.2 (G), R80.2
unnamed: Q116.2 (G), Q123.3 (D), R86.2
unnamed: Q117.3 (D), Q118.3 (D), Q119.2 (G), R81.2
unnamed: Q120.2 (G), Q126.3 (D), R88.2
unnamed: Q121.3 (D), Q122.1 (S)
unnamed: Q122.3 (D), Q123.2 (G), Q128.2 (G), R85.2
unnamed: Q124.3 (D), Q125.1 (S)
unnamed: Q125.3 (D), Q126.2 (G), Q127.2 (G), R87.2
unnamed: Q127.3 (D), Q128.1 (S)
unnamed: Q129.3 (D), Q130.3 (D), Q131.2 (G), R90.2
unnamed: Q132.2 (G), Q135.3 (D), R93.2
unnamed: Q133.3 (D), Q134.1 (S)
unnamed: Q134.3 (D), Q135.2 (G), R92.2
VCC: J1.2 (VCC), R2.1, R3.1, R4.1, R5.1, R8.1, R9.1, R10.1, R11.1, R12.1, R13.1, R14.1, R15.1, R16.1, R19.1, R20.1, R21.1, R22.1, R23.1, R24.1, R25.1, R26.1, R27.1, R30.1, R31.1, R32.1, R33.1, R34.1, R35.1, R36.1, R37.1, R38.1, R41.1, R42.1, R43.1, R44.1, R45.1, R46.1, R47.1, R48.1, R49.1, R52.1, R53.1, R54.1, R55.1, R56.1, R57.1, R58.1, R59.1, R60.1, R63.1, R64.1, R65.1, R66.1, R67.1, R68.1, R69.1, R70.1, R71.1, R74.1, R75.1, R76.1, R77.1, R78.1, R79.1, R80.1, R81.1, R82.1, R85.1, R86.1, R87.1, R88.1, R89.1, R90.1, R91.1, R92.1, R93.1

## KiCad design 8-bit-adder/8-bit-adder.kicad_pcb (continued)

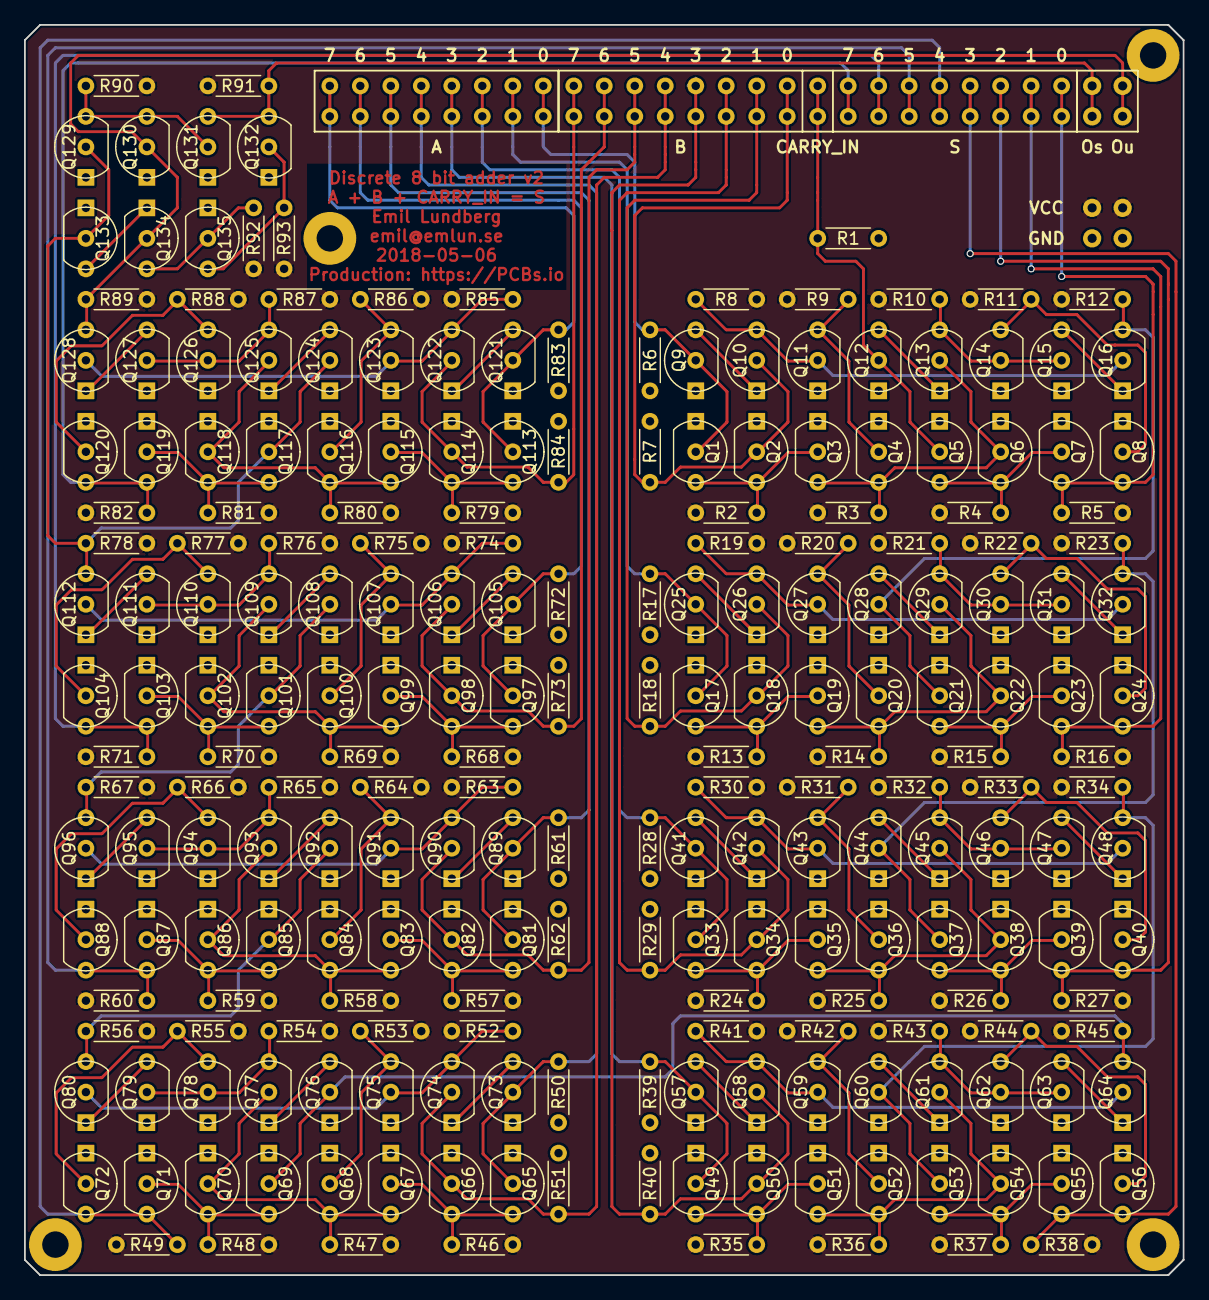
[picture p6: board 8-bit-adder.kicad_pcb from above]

Board: 2 copper layers, 96.5 x 104.1 mm, 234 parts (0 on the bottom side), 120 nets.

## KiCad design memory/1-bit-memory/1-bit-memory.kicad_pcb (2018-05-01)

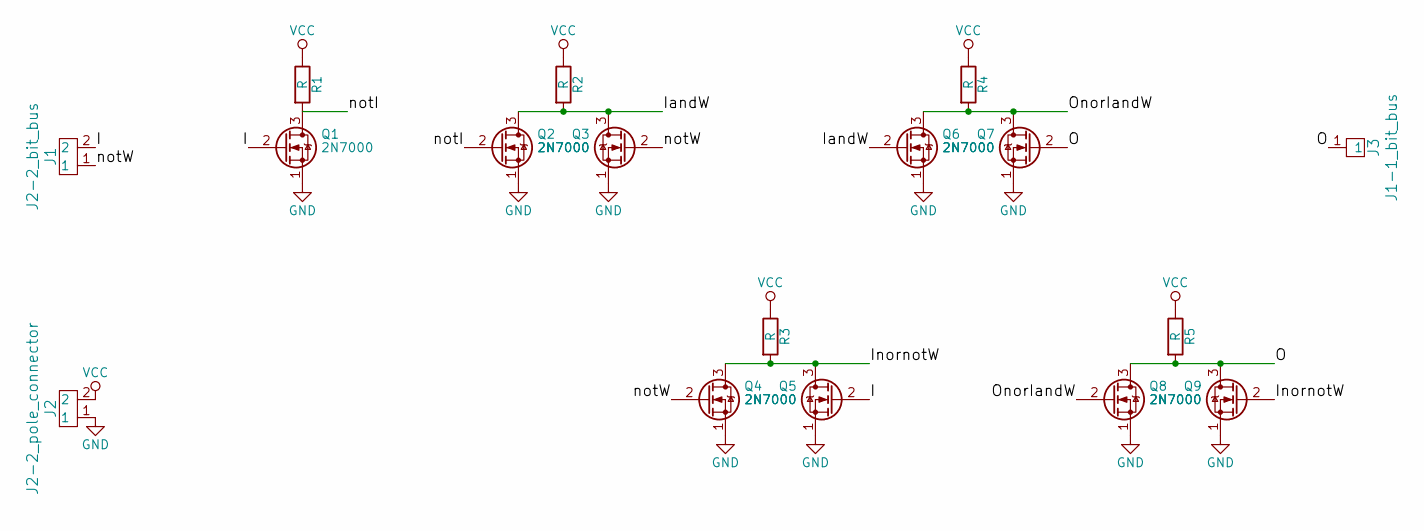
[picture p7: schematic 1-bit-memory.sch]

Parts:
J1: J2-2_bit_bus; J2-2_pole_connector
J2: J2-2_pole_connector
J3: J1-1_bit_bus
Q1, Q2, Q3, Q4, Q5, Q6, Q7, Q8, Q9: 2N7000; SOT-23
R1, R2, R3, R4, R5: R; R_0805

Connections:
/I: J1.2, Q1.2 (G), Q5.2 (G)
/IandW: Q2.3 (D), Q3.3 (D), Q6.2 (G), R2.2
/InornotW: Q4.3 (D), Q5.3 (D), Q9.2 (G), R3.2
/O: J3.1, Q7.2 (G), Q8.3 (D), Q9.3 (D), R5.2
/OnorIandW: Q6.3 (D), Q7.3 (D), Q8.2 (G), R4.2
/notI: Q1.3 (D), Q2.2 (G), R1.2
/notW: J1.1, Q3.2 (G), Q4.2 (G)
GND: J2.1, Q1.1 (S), Q2.1 (S), Q3.1 (S), Q4.1 (S), Q5.1 (S), Q6.1 (S), Q7.1 (S), Q8.1 (S), Q9.1 (S)
VCC: J2.2, R1.1, R2.1, R3.1, R4.1, R5.1

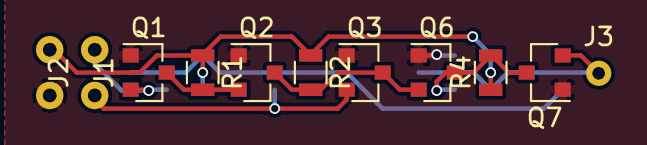
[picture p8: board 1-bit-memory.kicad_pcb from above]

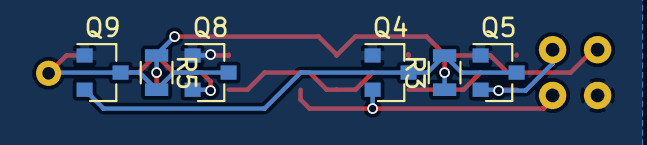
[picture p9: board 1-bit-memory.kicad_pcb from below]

Board: 2 copper layers, 17 parts (6 on the bottom side), 9 nets.

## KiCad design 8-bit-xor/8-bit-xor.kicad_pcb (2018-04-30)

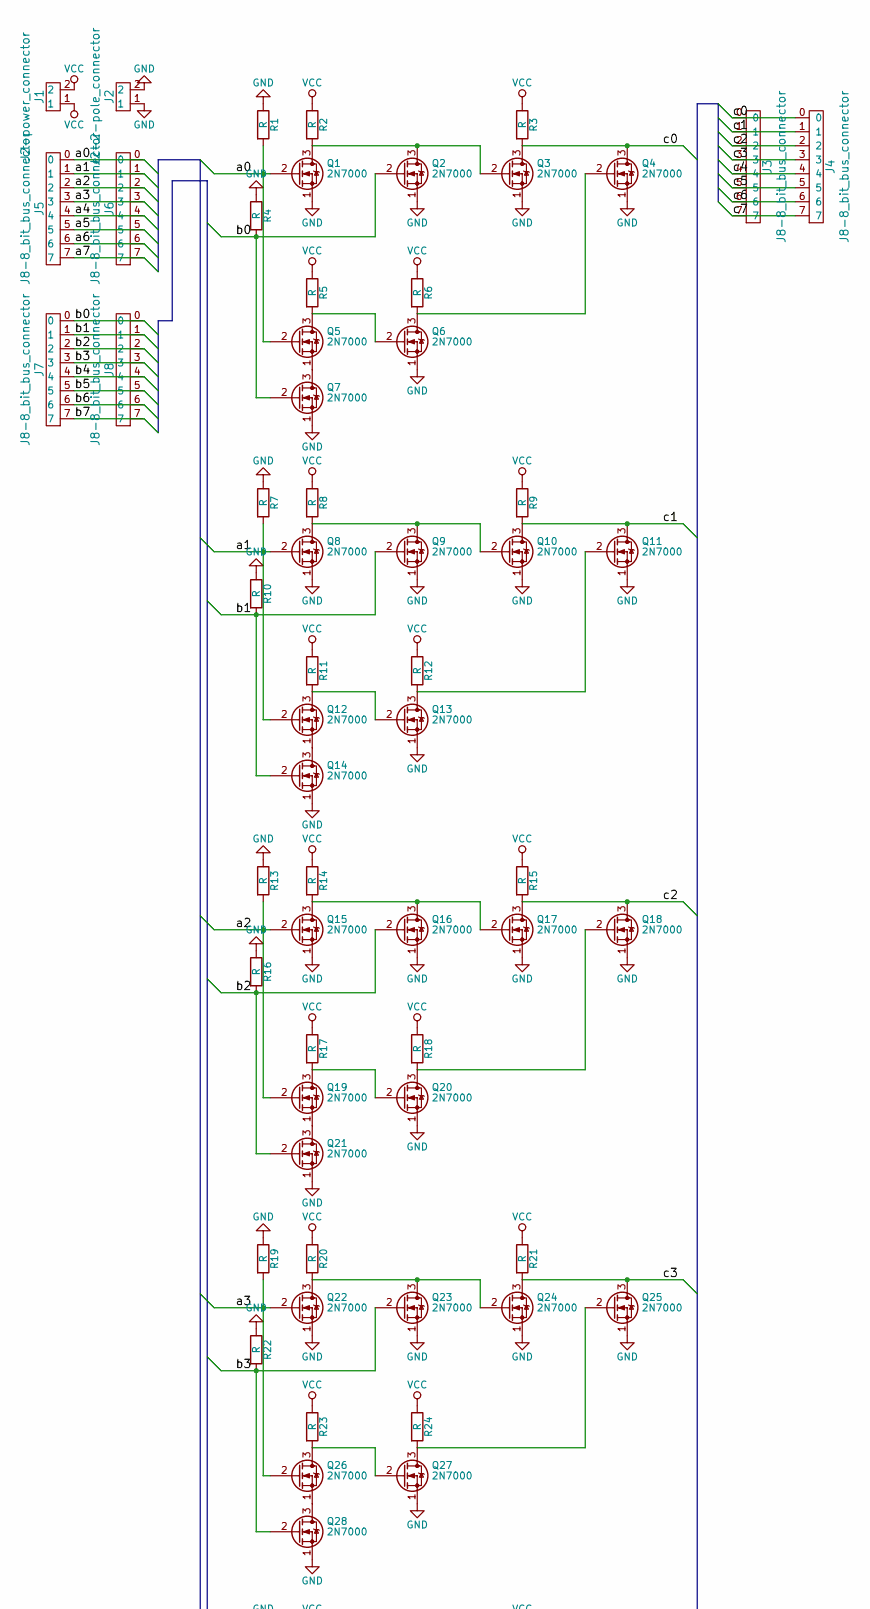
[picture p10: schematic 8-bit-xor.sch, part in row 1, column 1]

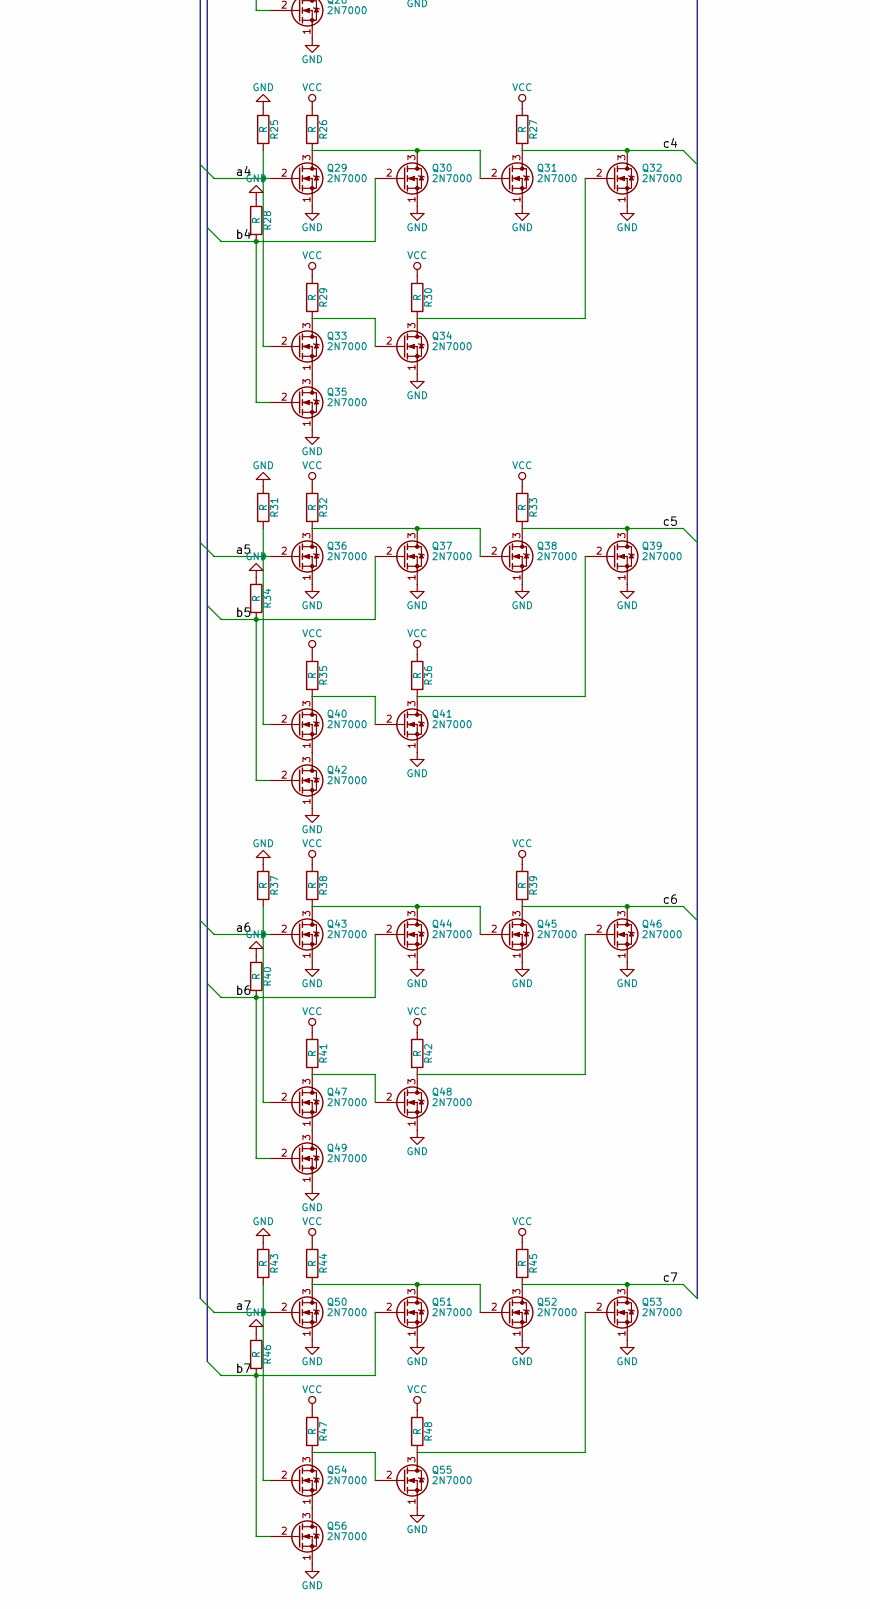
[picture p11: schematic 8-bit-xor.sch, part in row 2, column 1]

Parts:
J1: J2-power_connector; J2-2_pole_connector
J2: J2-2-pole_connector; J2-2_pole_connector
J3, J4, J5, J6, J7, J8: J8-8_bit_bus_connector
Q1, Q2, Q3, Q4, Q5, Q6, Q7, Q8, Q9, Q10, Q11, Q12, Q13, Q14, Q15, Q16, Q17, Q18, Q19, Q20, Q21, Q22, Q23, Q24, Q25, Q26, Q27, Q28, Q29, Q30, Q31, Q32, Q33, Q34, Q35, Q36, Q37, Q38, Q39, Q40, Q41, Q42, Q43, Q44, Q45, Q46, Q47, Q48, Q49, Q50, Q51, Q52, Q53, Q54, Q55, Q56: 2N7000; TO-92_Molded_Wide_Inline
R1, R2, R3, R4, R5, R6, R7, R8, R9, R10, R11, R12, R13, R14, R15, R16, R17, R18, R19, R20, R21, R22, R23, R24, R25, R26, R27, R28, R29, R30, R31, R32, R33, R34, R35, R36, R37, R38, R39, R40, R41, R42, R43, R44, R45, R46, R47, R48: R; R_Axial_DIN0204_L3.6mm_D1.6mm_P5.08mm_Horizontal

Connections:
/a0: J5.0, J6.0, Q1.2 (G), Q5.2 (G), R1.2
/a1: J5.1, J6.1, Q8.2 (G), Q12.2 (G), R7.2
/a2: J5.2, J6.2, Q15.2 (G), Q19.2 (G), R13.2
/a3: J5.3, J6.3, Q22.2 (G), Q26.2 (G), R19.2
/a4: J5.4, J6.4, Q29.2 (G), Q33.2 (G), R25.2
/a5: J5.5, J6.5, Q36.2 (G), Q40.2 (G), R31.2
/a6: J5.6, J6.6, Q43.2 (G), Q47.2 (G), R37.2
/a7: J5.7, J6.7, Q50.2 (G), Q54.2 (G), R43.2
/b0: J7.0, J8.0, Q2.2 (G), Q7.2 (G), R4.2
/b1: J7.1, J8.1, Q9.2 (G), Q14.2 (G), R10.2
/b2: J7.2, J8.2, Q16.2 (G), Q21.2 (G), R16.2
/b3: J7.3, J8.3, Q23.2 (G), Q28.2 (G), R22.2
/b4: J7.4, J8.4, Q30.2 (G), Q35.2 (G), R28.2
/b5: J7.5, J8.5, Q37.2 (G), Q42.2 (G), R34.2
/b6: J7.6, J8.6, Q44.2 (G), Q49.2 (G), R40.2
/b7: J7.7, J8.7, Q51.2 (G), Q56.2 (G), R46.2
/c0: J3.0, J4.0, Q3.3 (D), Q4.3 (D), R3.2
/c1: J3.1, J4.1, Q10.3 (D), Q11.3 (D), R9.2
/c2: J3.2, J4.2, Q17.3 (D), Q18.3 (D), R15.2
/c3: J3.3, J4.3, Q24.3 (D), Q25.3 (D), R21.2
/c4: J3.4, J4.4, Q31.3 (D), Q32.3 (D), R27.2
/c5: J3.5, J4.5, Q38.3 (D), Q39.3 (D), R33.2
/c6: J3.6, J4.6, Q45.3 (D), Q46.3 (D), R39.2
/c7: J3.7, J4.7, Q52.3 (D), Q53.3 (D), R45.2
GND: J2.1, J2.2, Q1.1 (S), Q2.1 (S), Q3.1 (S), Q4.1 (S), Q6.1 (S), Q7.1 (S), Q8.1 (S), Q9.1 (S), Q10.1 (S), Q11.1 (S), Q13.1 (S), Q14.1 (S), Q15.1 (S), Q16.1 (S), Q17.1 (S), Q18.1 (S), Q20.1 (S), Q21.1 (S), Q22.1 (S), Q23.1 (S), Q24.1 (S), Q25.1 (S), Q27.1 (S), Q28.1 (S), Q29.1 (S), Q30.1 (S), Q31.1 (S), Q32.1 (S), Q34.1 (S), Q35.1 (S), Q36.1 (S), Q37.1 (S), Q38.1 (S), Q39.1 (S), Q41.1 (S), Q42.1 (S), Q43.1 (S), Q44.1 (S), Q45.1 (S), Q46.1 (S), Q48.1 (S), Q49.1 (S), Q50.1 (S), Q51.1 (S), Q52.1 (S), Q53.1 (S), Q55.1 (S), Q56.1 (S), R1.1, R4.1, R7.1, R10.1, R13.1, R16.1, R19.1, R22.1, R25.1, R28.1, R31.1, R34.1, R37.1, R40.1, R43.1, R46.1
unnamed: Q1.3 (D), Q2.3 (D), Q3.2 (G), R2.2
unnamed: Q4.2 (G), Q6.3 (D), R6.2
unnamed: Q5.1 (S), Q7.3 (D)
unnamed: Q5.3 (D), Q6.2 (G), R5.2
unnamed: Q8.3 (D), Q9.3 (D), Q10.2 (G), R8.2
unnamed: Q11.2 (G), Q13.3 (D), R12.2
unnamed: Q12.1 (S), Q14.3 (D)
unnamed: Q12.3 (D), Q13.2 (G), R11.2
unnamed: Q15.3 (D), Q16.3 (D), Q17.2 (G), R14.2
unnamed: Q18.2 (G), Q20.3 (D), R18.2
unnamed: Q19.1 (S), Q21.3 (D)
unnamed: Q19.3 (D), Q20.2 (G), R17.2
unnamed: Q22.3 (D), Q23.3 (D), Q24.2 (G), R20.2
unnamed: Q25.2 (G), Q27.3 (D), R24.2
unnamed: Q26.1 (S), Q28.3 (D)
unnamed: Q26.3 (D), Q27.2 (G), R23.2
unnamed: Q29.3 (D), Q30.3 (D), Q31.2 (G), R26.2
unnamed: Q32.2 (G), Q34.3 (D), R30.2
unnamed: Q33.1 (S), Q35.3 (D)
unnamed: Q33.3 (D), Q34.2 (G), R29.2
unnamed: Q36.3 (D), Q37.3 (D), Q38.2 (G), R32.2
unnamed: Q39.2 (G), Q41.3 (D), R36.2
unnamed: Q40.1 (S), Q42.3 (D)
unnamed: Q40.3 (D), Q41.2 (G), R35.2
unnamed: Q43.3 (D), Q44.3 (D), Q45.2 (G), R38.2
unnamed: Q46.2 (G), Q48.3 (D), R42.2
unnamed: Q47.1 (S), Q49.3 (D)
unnamed: Q47.3 (D), Q48.2 (G), R41.2
unnamed: Q50.3 (D), Q51.3 (D), Q52.2 (G), R44.2
unnamed: Q53.2 (G), Q55.3 (D), R48.2
unnamed: Q54.1 (S), Q56.3 (D)
unnamed: Q54.3 (D), Q55.2 (G), R47.2
VCC: J1.1, J1.2, R2.1, R3.1, R5.1, R6.1, R8.1, R9.1, R11.1, R12.1, R14.1, R15.1, R17.1, R18.1, R20.1, R21.1, R23.1, R24.1, R26.1, R27.1, R29.1, R30.1, R32.1, R33.1, R35.1, R36.1, R38.1, R39.1, R41.1, R42.1, R44.1, R45.1, R47.1, R48.1

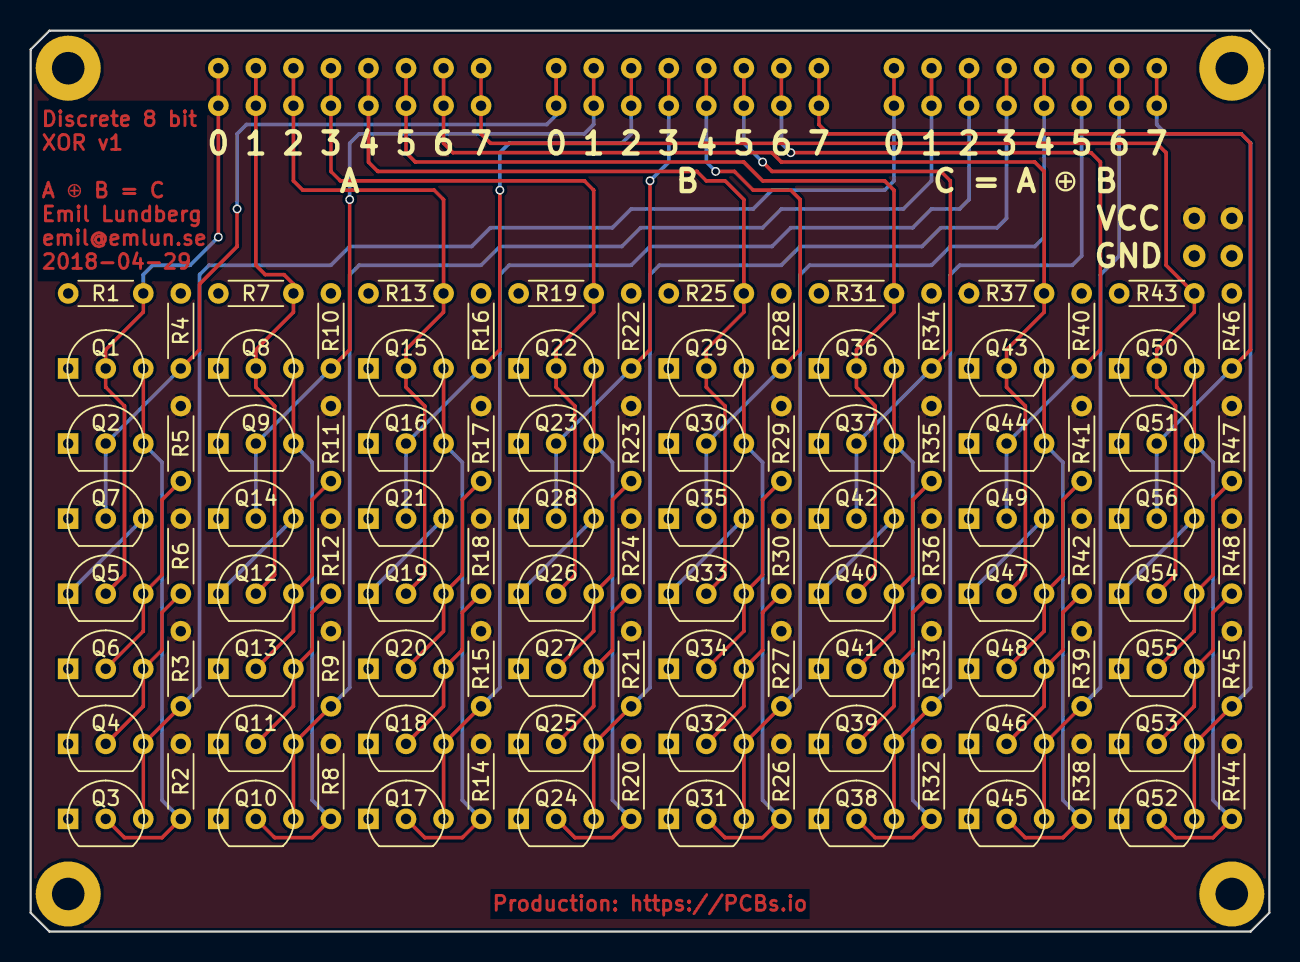
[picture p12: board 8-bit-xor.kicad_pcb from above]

Board: 2 copper layers, 83.8 x 61.0 mm, 112 parts (0 on the bottom side), 58 nets.

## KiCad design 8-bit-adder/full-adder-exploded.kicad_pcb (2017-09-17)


Board: 2 copper layers, 27 parts (0 on the bottom side), 16 nets.

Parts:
J1: J5-5_pole_connector
J2: J2-2_pole_connector
Q1, Q2, Q3, Q4, Q5, Q6, Q7, Q8, Q9, Q10, Q11, Q12, Q13, Q14, Q15, Q16: 2N7000; TO-92_Molded_Wide_Inline
R1, R2, R3, R4, R5, R6, R7, R8, R9: 1M; R_Axial_DIN0204_L3.6mm_D1.6mm_P5.08mm_Horizontal

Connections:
/A: J1.2, Q1.2, Q2.2
/AandB: Q5.3, Q7.2, R3.2
/AnandB: Q2.3, Q5.2, Q15.2, R2.2
/AnorB: Q1.3, Q4.3, Q6.2, R1.2
/AnorBnorAandB: Q6.3, Q7.3, Q10.2, Q11.2, R4.2
/B: J1.3, Q3.2, Q4.2
/C: J1.4, Q8.2, Q9.2
/CandD: Q12.3, Q16.2, R7.2
/Carry: J2.2, Q14.3, R9.2
/CnandD: Q9.3, Q12.2, Q14.2, R6.2
/CnorD: Q8.3, Q11.3, Q13.2, R5.2
/CnorDnorCandD: J2.1, Q13.3, Q16.3, R8.2
unnamed: Q2.1, Q3.3
unnamed: Q9.1, Q10.3
unnamed: Q14.1, Q15.3
VCC: J1.1, R1.1, R2.1, R3.1, R4.1, R5.1, R6.1, R7.1, R8.1, R9.1

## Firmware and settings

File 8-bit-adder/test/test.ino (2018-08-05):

// Adder test program
//
// Setup:
//  1. Connect pins PD2 - PD7, PB0 and PB1 to bits 0-7 of the S output
//  2. Connect pin PB2 to the Ou (unsigned overflow) output
//  3. Connect pin PB3 to the CARRY_IN input
//  4. Connect pin PB4 to a shift register serial data input
//  5. Connect pin PB5 to a shift register data clock input
//  6. Connect pin PC0 to a shift register storage clock input
//  7. Connect pin PC1 to the Os (signed overflow) output
//  8. Connect the serial data output of the shift register to the serial data input on a second shift register
//  9. Connect parallel data outputs 0-7 of the first shift register to bits 0-7 of the A input
// 10. Connect parallel data outputs 0-7 of the second shift register to bits 0-7 of the B input
// 11. Connect the output enable terminals of the shift registers to ground
// 12. Connect the master reset terminals of the shift registers to high voltage


const int OUTPUT_START = 2;
const int OUTPUT_LENGTH = 9;
const int CARRY_PIN = 11;
const int DATA_PIN = 12;
const int CLOCK_PIN = 13;
const int STORAGE_CLOCK_PIN = 14;
const int SIGNED_OVERFLOW_PIN = 15;

void setup() {
  Serial.begin(9600);
  pinMode(CARRY_PIN, OUTPUT);
  for (int i = OUTPUT_START; i < OUTPUT_START + OUTPUT_LENGTH; ++i) {
    pinMode(i, INPUT);
  }
  pinMode(SIGNED_OVERFLOW_PIN, INPUT);
  for (int i = DATA_PIN; i <= STORAGE_CLOCK_PIN; ++i) {
    pinMode(i, OUTPUT);
  }
}

void writeByte(byte b, unsigned int start_pin, unsigned int length) {
  for (unsigned int i = 0; i < length; ++i) {
    unsigned int c = (b >> i) % 2;
    digitalWrite(i + start_pin, c == 1 ? HIGH : LOW);
  }
}

int readParallel(unsigned int start_pin, unsigned int length) {
  unsigned int result = 0;
  for (unsigned int i = 0; i < length; ++i) {
    unsigned int bit = digitalRead(i + start_pin) == HIGH ? 1 : 0;
    unsigned int c = bit << i;
    result |= c;
  }
  return result;
}

void flashPin(unsigned int pin) {
  digitalWrite(pin, HIGH);
  delay(0);
  digitalWrite(pin, LOW);
  delay(0);
}

void writeSerialByte(unsigned int b, unsigned int data_pin, unsigned int clock_pin) {
  for (int i = 7; i >= 0; --i) {
    unsigned int c = (b >> i) & 1;
    digitalWrite(data_pin, c == 1 ? HIGH : LOW);
    flashPin(clock_pin);
  }
}

int unsigned_to_signed(unsigned int i) {
  const int j = i % 256;
  return j < 128 ? j : j - 256;
}

unsigned int test() {
  unsigned int correct = 0;
  unsigned int wrong = 0;
  for (unsigned int a = 0; a < 256; ++a) {
    int a_signed = unsigned_to_signed(a);

    for (unsigned int b = 0; b < 256; ++b) {
      int b_signed = unsigned_to_signed(b);

      for (unsigned int carry = 0; carry < 2; ++carry) {
        writeSerialByte(b, DATA_PIN, CLOCK_PIN);
        writeSerialByte(a, DATA_PIN, CLOCK_PIN);
        flashPin(STORAGE_CLOCK_PIN);
        digitalWrite(CARRY_PIN, carry == 1 ? HIGH : LOW);
        delay(1);
        const unsigned int expected = a + b + carry;
        const unsigned int result = readParallel(OUTPUT_START, OUTPUT_LENGTH);

        if (expected == result) {
          correct += 1;
        } else {
          wrong += 1;
          Serial.print(a);
          Serial.print(" + ");
          Serial.print(b);
          Serial.print(" + ");
          Serial.print(carry);
          Serial.print(" = ");
          Serial.print(result);
          Serial.print(" WRONG (expected ");
          Serial.print(expected);
          Serial.print(")");
          Serial.println();
        }

        const int signed_result = unsigned_to_signed(result);
        const int signed_expected_unwrapped = a_signed + b_signed + carry;
        const int signed_expected = signed_expected_unwrapped > 127 ? signed_expected_unwrapped - 256 : signed_expected_unwrapped < -128 ? signed_expected_unwrapped + 256 : signed_expected_unwrapped;
        const bool signed_overflow_result = digitalRead(SIGNED_OVERFLOW_PIN) == HIGH;
        const bool signed_overflow_expected = signed_expected_unwrapped < -128 || signed_expected_unwrapped > 127;

        if (signed_expected == signed_result && signed_overflow_result == signed_overflow_expected) {
          correct += 1;
        } else {
          wrong += 1;

          Serial.print(a_signed);
          Serial.print(" + ");
          Serial.print(b_signed);
          Serial.print(" + ");
          Serial.print(carry);
          Serial.print(" = ");
          Serial.print(signed_result);
          Serial.print(" (Os: ");
          Serial.print(signed_overflow_result);
          Serial.print(")");
          Serial.print(" WRONG (expected ");
          Serial.print(expected);
          Serial.print(" (Os: ");
          Serial.print(signed_overflow_expected);
          Serial.print("))");
          Serial.println();
        }
      }
    }
    Serial.print(a);
    Serial.print(" correct: ");
    Serial.print(correct);
    Serial.print(", wrong: ");
    Serial.print(wrong);
    Serial.println();
  }
  return wrong;
}

void loop() {
  unsigned int wrong = test();
  writeSerialByte(0, DATA_PIN, CLOCK_PIN);
  writeSerialByte(0, DATA_PIN, CLOCK_PIN);
  writeSerialByte(wrong, DATA_PIN, CLOCK_PIN);
  flashPin(STORAGE_CLOCK_PIN);

  Serial.println("Done!");
  Serial.print("Wrong: ");
  Serial.print(wrong);
  Serial.println();

  delay(600000);
}

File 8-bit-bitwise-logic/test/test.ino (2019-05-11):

// 8 bit bitwise logic test program
//
// Setup:
//  1. Connect pins PD2 - PD7, PB0 and PB5 to bits 0-7 of the output to test
//  2. Connect pin PC0 to a shift register serial data input
//  3. Connect pin PC1 to a shift register data clock input
//  4. Connect pin PC2 to a shift register storage clock input
//  5. Connect 2 shift registers in series
//  6. Connect the parallel data outputs 0-7 of the first shift register to bits 0-7 of the A input
//  7. Connect the parallel data outputs 0-7 of the second shift register to bits 0-7 of the B input
//  8. Connect the output enable terminals of the shift registers to ground
//  9. Connect the master reset terminals of the shift registers to high voltage
// 10. Modify the expression for the `expected` variable as needed.
//
// Beware that the OR output header will collide with the TX/RX pins on The Cuttle
// if mounted on the same standard breadboard.


const int OUTPUT_PINS[] = {2, 3, 4, 5, 6, 7, 8, 13};
const int OUTPUT_LENGTH = 8;
const int DATA_PIN = 14;
const int CLOCK_PIN = 15;
const int STORAGE_CLOCK_PIN = 16;

const int TRIALS = 1000;

void setup() {
  Serial.begin(9600);
  for (int i = 0; i < OUTPUT_LENGTH; ++i) {
    pinMode(OUTPUT_PINS[i], INPUT);
  }
  for (int i = DATA_PIN; i <= STORAGE_CLOCK_PIN; ++i) {
    pinMode(i, OUTPUT);
  }
}

int readParallel(unsigned int* pins, unsigned int length) {
  unsigned int result = 0;
  for (unsigned int i = 0; i < length; ++i) {
    unsigned int bit = digitalRead(pins[i]) == HIGH ? 1 : 0;
    unsigned int c = bit << i;
    result |= c;
  }
  return result;
}

void flashPin(unsigned int pin) {
  digitalWrite(pin, HIGH);
  delay(0);
  digitalWrite(pin, LOW);
  delay(0);
}

void writeSerialByte(unsigned int b, unsigned int data_pin, unsigned int clock_pin) {
  for (int i = 0; i < 8; ++i) {
    unsigned int c = (b >> i) & 1;
    digitalWrite(data_pin, c == 1 ? HIGH : LOW);
    flashPin(clock_pin);
  }
}

unsigned int test() {
  unsigned int correct = 0;
  unsigned int wrong = 0;

  for (unsigned int n = 0; n < TRIALS; ++n) {
    const unsigned int a = random(0, 256);
    const unsigned int b = random(0, 256);

    writeSerialByte(a, DATA_PIN, CLOCK_PIN);
    writeSerialByte(b, DATA_PIN, CLOCK_PIN);
    flashPin(STORAGE_CLOCK_PIN);
    delay(1);

    const unsigned int result = readParallel(OUTPUT_PINS, OUTPUT_LENGTH);
    const unsigned int expected = ~(a | b);

    if (expected == result) {
      correct += 1;
      Serial.print("A = ");
      Serial.print(a, HEX);
      Serial.print(", B = ");
      Serial.print(b, HEX);
      Serial.print(", O = ");
      Serial.print(result, HEX);
      Serial.println(" OK");
    } else {
      wrong += 1;
      Serial.print("A = ");
      Serial.print(a, HEX);
      Serial.print(", B = ");
      Serial.print(b, HEX);
      Serial.print(", O = ");
      Serial.print(result, HEX);
      Serial.print(" WRONG (expected ");
      Serial.print(expected, HEX);
      Serial.println(")");
    }
  }

  return wrong;
}

void loop() {
  unsigned int wrong = test();

  Serial.println("Done!");
  Serial.print("Wrong: ");
  Serial.print(wrong);
  Serial.println();

  delay(600000);
}

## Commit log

2017-09-17 Initial commit: Add full adder schematics
    [full-adder-exploded.kicad_pcb, full-adder-v1.kicad_pcb]
2017-09-17 Add 8 bit adder schematics
    [8-bit-adder.kicad_pcb, 8-bit-adder.sch]
2017-09-17 Fix library paths and add missing resistor annotations
    [8-bit-adder.kicad_pcb, 8-bit-adder.sch]
2017-09-17 Generate gerber files for 8 bit adder v1
    [8-bit-adder-B.Cu.gbl, 8-bit-adder-B.Mask.gbs, 8-bit-adder-Edge.Cuts.gm1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]
2017-09-17 Add carry input to 8 bit adder
    [8-bit-adder-B.Cu.gbl, 8-bit-adder-B.Mask.gbs, 8-bit-adder-Edge.Cuts.gm1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]
2017-09-17 Generate drill file correctly
    [8-bit-adder-NPTH.drl, 8-bit-adder.drl]
2018-04-29 Commit old changes
    [8-bit-adder.kicad_pcb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]
2018-04-30 Tweak labels on TO-92 footprint
2018-04-30 Tweak label on resistor footprint
2018-04-30 Add 8-bit XOR schematics
    [8-bit-xor.kicad_pcb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]
2018-05-01 Add memory schematics
    [1-bit-memory.kicad_pcb, 1-bit-memory.sch, 8-bit-memory.kicad_pcb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]
2018-05-01 Rename 8-bit-memory project to 8-bit-memory-smd
    [8-bit-memory-smd.kicad_pcb, 8-bit-memory-smd.sch]
2018-05-01 Copy 8-bit-memory-smd project to 8-bit-memory-tht
    [8-bit-memory-tht.kicad_pcb, 8-bit-memory-tht.sch]
2018-05-01 Add double versions of bus connectors
2018-05-01 Fix center of TO-92 footprint
2018-05-01 Finish THT memory board layout
    [8-bit-memory-tht.kicad_pcb, 8-bit-memory-tht.sch]
2018-05-01 Add Gerber files for 8-bit-memory-tht
    [8-bit-memory-tht-B.Cu.gbl, 8-bit-memory-tht-B.Mask.gbs, 8-bit-memory-tht-Edge.Cuts.gm1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]
2018-05-06 Fix pin types of power connector component
2018-05-06 Update adder circuit to revision 2
    [8-bit-adder.kicad_pcb, 8-bit-adder.sch]
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2018-05-06 Regenerate 8-bit-adder plot files
    [8-bit-adder-B.Cu.gbl, 8-bit-adder-B.Mask.gbs, 8-bit-adder-Edge.Cuts.gm1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]
2018-06-24 Add footprints used by Crazy Circuit Conundrum for Midnight Sun CTF
2018-06-30 Add battery holder footprints
2018-06-30 Add outline around J1x2-double_1_bit_bus footprint
2018-06-30 Migrate TO-92 Molded Wide Inline footprint
2018-06-30 Add THT memory circuit v2
    [8-bit-memory-tht-2018-06-24-21-44-00.sch, 8-bit-memory-tht.kicad_pcb]
2018-06-30 Rescue old components
    [8-bit-memory-tht.sch]
2018-06-30 Add sketch of bus selector circuit
    [bus-selector.kicad_pcb, bus-selector.sch]
2018-06-30 Add symbol for adder circuit
2018-06-30 Add symbol for XOR circuit
2018-06-30 Add symbol for memory circuit
2018-06-30 Prettify PWR symbol
    [bus-selector.sch]
2018-07-19 Print adder test results to serial monitor
2018-07-19 Add test program for XOR circuit
2018-07-19 Add test program for memory circuit
2018-07-19 Finish bus selector connection diagram
    [bus-selector.sch]
2018-07-19 Greatly simplify bus selector circuit
    [bus-selector.sch]
2018-07-19 Additional tweaks to bus selector circuit diagram
    [bus-selector.sch]
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2018-07-19 Finish PCB layout of bus selector
    [bus-selector.kicad_pcb]
2018-07-19 Add Gerber files for bus selector
    [bus-selector-B.Cu.gbl, bus-selector-B.Mask.gbs, bus-selector-B.Paste.gbp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]
2018-07-19 Add 8 bit bitwise logic circuit
    [8-bit-bitwise-logic-2018-06-30-11-40-24.sch, 8-bit-bitwise-logic.kicad_pcb, 8-bit-bitwise-logic.sch]
2018-07-19 Add Gerber files for 8-bit bitwise logic circuit
    [8-bit-bitwise-logic-B.Cu.gbl, 8-bit-bitwise-logic-B.Mask.gbs, 8-bit-bitwise-logic-B.SilkS.gbo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]
2018-07-19 Add pull-down resistors to bus selector
    [bus-selector.sch]
2018-07-19 Fix alignment of PWR-2_pole_power_connector component
    [bus-selector.sch]
2018-07-29 Add pull-down resistors to bus selector inputs
    [bus-selector.kicad_pcb]
2018-07-30 Update power connector component in bitwise logic schematic
    [8-bit-bitwise-logic.sch]
2018-07-31 Fix pin types in memory circuit symbol
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2018-08-01 Fix reference texts in bus connector footprints
2018-08-01 Remove endianness indicators from 8-bit bus connector footprint
2018-08-01 Add double 3- and 4-bit bus connector footprints
2018-08-02 Unify pin header footprints at 1,4mm pads with 0,7mm hole
2018-08-02 Unify pin header footprints at 1,524mm pads with 0,762mm hole
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2018-08-02 Add silkscreen outline to bitwise logic circuit footprint
2018-08-02 Add silkscreen outline to 8-input NOR circuit footprint
2018-08-02 Add ALU control unit schematic
    [alu-control-unit.sch]
2018-08-02 Flip orientation of XOR subcircuit buses in ALU control unit
    This makes routing these buses easier, while not affecting the output.
    [alu-control-unit.sch]
2018-08-02 Rearrange bus wiring in ALU control unit schematic
    [alu-control-unit.sch]
2018-08-02 Add first draft of ALU control unit PCB layout
    [alu-control-unit.kicad_pcb]
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2018-08-02 Replace footprint J2x2-double_2_pole_connector with PWR-double_2_pole_power_connector
    [alu-control-unit.sch]
2018-08-02 Fix 3D settings for new pin header footprints
2018-08-02 Add 3D settings for 1x2 pin header footprint
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2018-08-02 Touch up ALU control unit PCB layout
    [alu-control-unit.kicad_pcb]
2018-08-02 Fix reference text in 8-input NOR footprint
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2018-08-03 Rearrange 8-input NOR footprint to match the working prototype
    [alu-control-unit.kicad_pcb]
2018-08-03 Assign the unassigned ALU op code to echo operand A
    [alu-control-unit.sch]
2018-08-03 Update ALU PCB layout with new operation code
    [alu-control-unit.kicad_pcb]
2018-08-03 Add pull-down resistors to ALU control unit inputs
    [alu-control-unit.sch]
2018-08-03 Wire up ALU pull-down resistors
    [alu-control-unit.kicad_pcb]
2018-08-03 Cleanup tracks and vias
    [alu-control-unit.kicad_pcb]
2018-08-03 Fix a track too close to a mounting hole
2018-08-03 Make pull-down resistor connections visible on front side
    [alu-control-unit.kicad_pcb]
2018-08-03 Add VCC and GND labels to ALU control unit PCB
    [alu-control-unit.kicad_pcb]
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2018-08-05 Make adder test program work with 1M resistors
2019-05-11 Add ? to zero detector subsystem label
    [alu-control-unit.kicad_pcb]
2019-05-11 Fix order of boolean operations in opcodes label
    [alu-control-unit.kicad_pcb]
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
